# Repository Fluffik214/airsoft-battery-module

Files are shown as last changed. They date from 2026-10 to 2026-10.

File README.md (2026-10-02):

# Airsoft Battery Module

This is a USB-C PD charger and cell monitor for a **3S LiPo** that lives in an airsoft stock tube. It has one USB-C port. A PD charger charges the pack through it, and a phone plugged into the same port shows each cell's voltage and charge % in the companion Android app.

| | |
|---|---|
| Board | 135 × 21 mm, 2 layers, SMT only, no BGA |
| Pack | 3S LiPo (made for an iPower 1450 mAh stick). Deans main lead, JST-XH balance plug |
| Charging | USB-C PD at 15 V (CH224K) → BQ25798 buck-boost charger |
| Monitoring | BQ7692003 (per-cell voltage, NTC, balancing) → STM32F042 → USB CDC |
| Idle drain | about 1 µA when unplugged |

## How it works

- **One port, two jobs.** On a PD charger the module charges. On a phone it only reports (5 V never charges, so the phone isn't drained). It never does both at once.
- **Charging rules:**
  - It starts after USB has stayed between 12 and 17 V for 5 s, then charges to your preset: Full, a custom %, Storage (3.80 V/cell) or Off.
  - If USB goes above 17 V, charging is cut immediately.
- **Per-cell control, like a hobby balance charger.** When a cell is full, it is held there and bled while the current is turned down, so the other cells can catch up. No cell goes more than 10 mV over the target.
- **JP2 solder jumper (back of the board).** Open (default) = slow charge, 700 mA. Bridged = fast charge, 1.4 A. Both currents can be changed in the app.
- **Event log in flash.** Faults (over-voltage, over-temperature, bad cell…) and a report for every charge are stored on the module. The app shows them the next time a phone is connected.

## Repository layout

| Path | Contents |
|---|---|
| `usbc pd airsoft module.kicad_*` | KiCad 10 project: schematic, routed PCB, design rules |
| `schematic.pdf`, `bom.csv` | Schematic printout and bill of materials |
| `DESIGN_NOTES.md` | Hardware notes: power path, pinouts, checks before first power-up |
| `layout_work/` | Python scripts that generated the schematic and placed/routed the PCB |
| `firmware/` | STM32F042 firmware: bare-metal C plus TinyUSB. **`firmware/README.md` is the full guide**, covering protocol, settings, safety rules and how to customize |
| `android/` | Android app: Kotlin, Jetpack Compose, Material 3 |
| `release/` | Prebuilt firmware (`.bin` / `.hex`) and app (`.apk`) |
| `production/` | Gerber zip for the board house, drill files, pick-and-place, BOM, assembly drawings, and `ORDERING.md` (fab settings) |

## Quick start

1. **Flash the firmware.** A blank chip starts in the USB DFU bootloader. You can also bridge JP1 while plugging in. Then:
   ```
   dfu-util -a 0 -s 0x08000000:leave -D release/airsoft_charger.bin
   ```
   STM32CubeProgrammer works too.
2. **Install the app.** Copy `release/PDCharger-1.0.0.apk` to the phone and install it.
3. **Check the pack.** Plug the module into the phone with a USB-C cable and open the app.
4. **Charge it.** Put the module on a USB-C PD charger that offers 15 V (or 12 V).

### Building from source

- **Firmware:** needs `arm-none-eabi-gcc` (tested with xPack 15.2.1). Run:
  ```
  python firmware/build.py --gcc <path-to-toolchain-bin>
  ```
- **App:** needs JDK 17 and the Android SDK. Run:
  ```
  cd android && ./gradlew assembleRelease
  ```

## Safety

LiPo batteries can catch fire. This is a hobby project with **no warranty**. Check `DESIGN_NOTES.md` before the first power-up. In particular, confirm that the balance plug's pin 1 is the pack's negative wire.

## License

© Fluff. Licensed under **[Creative Commons Attribution-NonCommercial-ShareAlike 4.0](LICENSE)** (CC BY-NC-SA 4.0):

- You may copy, build and change this project for **non-commercial** use, if you credit the author and share your changes under the same license.
- **Commercial use, including selling boards, kits or devices built from this design, needs written permission from the author.**

Third-party code in `firmware/lib/` keeps its own license:

- **TinyUSB:** MIT, see `firmware/lib/tinyusb/LICENSE`.
- **ARM CMSIS core headers:** Apache-2.0 (SPDX header in each file).
- **ST device headers:** Apache-2.0, see `firmware/lib/cmsis/LICENSE-ST-cmsis-device-f0.md`.

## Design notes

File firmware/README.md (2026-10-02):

# Airsoft PD Charger: firmware guide

This firmware runs on the **STM32F042F6P6** of the Rev A board. It is bare-metal C: CMSIS registers plus TinyUSB for the USB serial port. There is no HAL and no RTOS.

| | |
|---|---|
| Flash used | **26.0 KB of 30 KB** (+ 1 KB event-log page + 1 KB settings page) |
| RAM used | **3.0 KB of 6 KB** (plus 1 KB reserved for the stack) |
| Clock | 48 MHz HSI48, trimmed to USB by CRS (no crystal) |
| USB | CDC-ACM virtual serial port. VID/PID `0x1209/0x0001` (pid.codes *test* ID) |
| Output | `build/airsoft_charger.bin` / `.hex` (also copied to `../release/`) |

---

## 1. What the module does

> **One USB-C port.** The module is *either* on a charger (charging, no phone) *or* on a phone (talking, 5 V, never charging). It is never both at once. The app therefore never sees a charge live. It sets the plan beforehand and reads the **charge report** from the log afterwards.

Charging is decided by **the USB voltage only**:

```
              USB-C plugged in → MCU boots (powered from VBUS via the LDO)
                                   │
          ┌────────────────────────┼─────────────────────────┐
     VBUS < minvin (12 V)     12 V ≤ VBUS ≤ 17 V        VBUS > 17 V
     phone / 5 V charger      (PD charger at 15 V)      (broken charger)
          │                        │                         │
     monitor only             stays in window for       charging cut at once
     (state HOST if the       cfg.wait_s (default 5 s)  (CHG_EN low in < 1 ms),
      app is talking,               │                   fault logged; must be back
      else MONITOR)           charge by the plan        in the window for 5 s again
                       ┌───────────┼──────────────┐
                  mode 0: to   mode 1: storage  mode 2: off
                  tgt %        (bleed if above) (monitor)
                       └── charger stops itself at the target (CV + termination)
     USB unplugged → (optional balancing for "bun" minutes) → charger SHUTDOWN
                   + monitor SHIP + PWR_HOLD low = ~1 µA total
```

- **Phone:** it gives 5 V, so the module never charges from it. It only answers the app's requests (`s?`, `c?`, `log?` …). Talking to the app does **not** affect charging any more; `host` is just information.
- **PD charger:** 15 V lands in the window, and after 5 s the module charges to the preset % and stops.
- **Over-voltage:** `app_fast()` runs on every main-loop pass, not just every 250 ms. After 3 readings in a row above 17 V it drops `CHG_EN`, which switches the charger off in hardware through Q1 and /CE. As a second layer, the BQ25798's own input over-voltage cutoff is set to 18 V (`VAC_OVP`, re-applied every 5 s).

> The limit is `VBUS_MAX_MV` = 17000 in `board.h`. PD chargers may give up to 15.75 V when asked for 15 V, which leaves about 1.2 V of margin for ADC error.

## 2. File map

| File | What it is | Edit it when… |
|---|---|---|
| `src/board.h` | Pin map, I²C addresses, VBUS divider, version strings | you change the schematic or bump the version |
| `src/main.c` | Startup order, main loop, USB send/receive, `delay_hook` | you change the loop timing or USB handling |
| `src/app.c / app.h` | **Everything that matters**: state machine, safety, balancing, LED, JSON status, commands | you change behavior |
| `src/config.c / config.h` | Settings struct, defaults, allowed ranges, flash save with CRC | you add or change a setting |
| `src/soc.c / soc.h` | LiPo voltage↔% table, IR correction while charging | your packs have a different curve |
| `src/log.c / log.h` | Event log in its own flash page (faults, charge start/end, watchdog resets) | you want to log more things |
| `src/bq25798.c / .h` | Charger IC driver (registers, ADC readout, enable/HIZ/shutdown) | you need another charger feature |
| `src/bq76920.c / .h` | Cell monitor driver (CRC I²C, gain/offset, NTC, balance, ship) | you change cell wiring or the NTC |
| `src/hw.c / hw.h` | Clock, SysTick, GPIO, ADC, I²C, LED PWM, watchdog, flash, ROM-bootloader jump | low-level hardware changes |
| `src/startup.c` | Vector table and reset handler (calls `boot_check()` for DFU) | almost never |
| `stm32f042f6.ld` | Linker script: 30 KB code + 1 KB `LOG` page + 1 KB `CFG` page + 6 KB RAM | almost never |
| `src/usb_descriptors.c` | USB VID/PID, names, serial number (from the chip UID) | **before selling anything** (VID/PID) |
| `src/tusb_config.h` | TinyUSB options and buffer sizes | rarely |
| `lib/tinyusb` | TinyUSB (trimmed to device + CDC + STM32 FSDEV) | never |
| `lib/cmsis` | ARM/ST register headers | never |
| `build.py` | Build script (no `make` needed) | adding source files |

---

## 3. Building

You need an `arm-none-eabi-gcc` toolchain. The one used here is xPack GCC 15.2.1, unpacked at `C:\Users\duzik\.xpack\arm-gcc`.

> **Windows tip:** keep the toolchain in a short path. GCC fails with "machine/_default_types.h: No such file" when its path is longer than about 260 characters.

```
cd firmware
python build.py --gcc C:/Users/duzik/.xpack/arm-gcc/bin
```

You can also put the toolchain on `PATH` or set the `ARM_GCC_BIN` environment variable. `python build.py clean` deletes `build/`.

The build prints flash and RAM usage at the end. **Keep FLASH under 30 KB.** The last two pages hold the event log and your settings, and the linker refuses to overflow into them.

To add a `.c` file, append it to `SRC` in `build.py`.

---

## 4. Flashing

The chip has a USB DFU bootloader in ROM, so no programmer is needed.

| Situation | How to get into the bootloader |
|---|---|
| Brand-new (blank) chip | Plug in USB. A blank STM32F042 boots straight into the ROM bootloader. |
| Firmware running | App → Settings → Advanced → **Bootloader (DFU)**, or send `dfu` over serial |
| Firmware broken | Bridge **JP1** (BOOT0 to 3V3) while plugging in USB |
| SWD instead | Test pads TP5 SWDIO, TP6 SWCLK, TP7 3V3, TP8 GND (back side) plus an ST-Link |

Then flash from a PC:

```
STM32CubeProgrammer:  Port = USB → Connect → Open airsoft_charger.bin at 0x08000000 → Download
dfu-util:             dfu-util -a 0 -s 0x08000000:leave -D airsoft_charger.bin
```

On Windows, dfu-util needs the WinUSB driver for "STM32 BOOTLOADER" (use Zadig). CubeProgrammer installs its own driver.

Settings live in the 1 KB page at `0x08007C00` and the event log at `0x08007800`. Flashing only the `.bin` keeps both. A full chip erase resets the settings to defaults and empties the log.

---

## 5. Settings (stored in flash)

All settings are set with `set <key> <value>`, and `save` writes them to flash. Defaults and limits are in `config.c`: change `config_defaults()` and the `fields[]` table.

| Key | Meaning | Default | Range | Unit |
|---|---|---|---|---|
| `mode` | 0 = charge to `tgt`, 1 = storage, 2 = never charge | 0 | 0–2 | |
| `tgt` | charge target in mode 0 (100 = full = `vcell`) | 100 | 50–100 | % |
| `wait` | USB must stay in the 12–17 V window this long before charging starts | 5 | 1–600 | s |
| `vcell` | full-charge voltage per cell | 4200 | 4000–4200 | mV |
| `ichs` | **slow** charge current, used while JP2 is open (default) | 700 | 100–3000 | mA |
| `ichg` | **fast** charge current, used when JP2 is bridged | 1400 | 100–3000 | mA |
| `iin` | USB input current limit (1.5 A keeps an 18 W 12 V charger and a 20 W 15 V charger within rating) | 1500 | 500–3000 | mA |
| `stor` | storage voltage per cell | 3800 | 3700–3900 | mV |
| `minvin` | lower edge of the charging window (the upper edge is `VBUS_MAX_MV` = 17 V in `board.h`) | 12000 | 9000–15000 | mV |
| `bal` | balancing on/off | 1 | 0–1 | |
| `balth` | balance when the cell spread is above this | 15 | 5–60 | mV |
| `balmin` | never bleed a cell below this voltage | 3900 | 3500–4150 | mV |
| `bun` | keep balancing on pack power after unplug | 0 | 0–60 | min |
| `imb` | refuse to charge above this cell spread | 300 | 50–500 | mV |
| `tmax` | max pack temperature while charging | 45 | 35–60 | °C |
| `cap` | pack capacity (used for the ETA) | 1450 | 200–10000 | mAh |
| `led` | LED brightness | 40 | 0–100 | % |
| `rate` | status report interval | 500 | 200–5000 | ms |

**How `tgt` becomes a voltage:** `target_mv()` in `app.c` runs `soc_to_mv(tgt)` (the inverse of the OCV table) and caps the result at `vcell`. The charger's VREG is set to 3 × that value. The BQ25798 then does a normal CC/CV charge to that voltage and terminates by itself.

| Target | Per cell | Pack |
|---|---|---|
| 80 % | ≈ 4.04 V | ≈ 12.1 V |
| 100 % | 4.20 V | 12.6 V |

**Adding a new setting:**

1. Add a field to `config_t` before `crc`.
2. Set its default in `config_defaults()`.
3. Add a line to `fields[]`.
4. Add it to `send_cfg()` in `app.c`.
5. If the layout changed, bump `CFG_MAGIC` so old flash contents are ignored instead of misread.
6. In the app, add it to `ConfigKey` in `Models.kt`.

---

## 6. Serial protocol (what the app speaks)

The protocol is plain text lines ending in `\n`. Any terminal works at any baud rate, but **DTR must be on**, because the firmware only sends while a terminal is open. Every reply is a single JSON line.

### Commands

| Command | Reply / effect |
|---|---|
| `s?` | status line now (status also streams every `rate` ms) |
| `c?` | `{"t":"cfg", …all keys…}` |
| `i?` | `{"t":"i","fw":"1.0.0","hw":"RevA","uid":"…","chg":1,"bms":1}` (chg/bms = chips found) |
| `set <key> <int>` | `{"t":"ok","m":"<key>"}` then the cfg line, or `{"t":"err","m":"bad key/value"}` |
| `save` | writes the settings to flash |
| `defaults` | resets the settings in RAM (send `save` afterwards to keep them) |
| `mode charge\|storage\|monitor` | same as `set mode 0/1/2` |
| `reboot` | soft reset |
| `dfu` | jump to the ROM USB bootloader |
| `ship` | refused while USB is present (shipping happens automatically on unplug) |
| `log?` | the whole event log: one `{"t":"log","b":boot,"s":sec,"c":code,"v":value}` per entry (oldest first), then `{"t":"logend","n":count,"boot":current}` |
| `logclr` | erase the event log |

### Status line

```json
{"t":"s","st":"HOST","md":"charge","src":"LOW","vbus":5040,"ibus":0,"pack":11520,"ibat":0,
 "c":[3841,3838,3840],"p":[48,47,48],"soc":48,"tp":243,"tc":312,"bal":0,"flt":256,"chg":0,
 "eta":-1,"up":12,"host":1,"arm":-1,"tgt":4200}
```

| Field | Meaning |
|---|---|
| `st` | state (see the next table) |
| `md` | `charge` / `storage` / `monitor` |
| `src` | `NONE` (< 4 V), `LOW` (below `minvin`), `PD` (in the window), `HIGH` (> 17 V) |
| `vbus` / `ibus` | USB voltage (mV) and current (mA) |
| `pack` / `ibat` | pack voltage (mV) and battery current (mA, + = charging) |
| `c[]` | cell 1–3 voltages (mV) |
| `p[]` | per-cell % |
| `soc` | pack % (average of the cells, IR-corrected while charging) |
| `tp` / `tc` | pack NTC / charger die temperature, 0.1 °C |
| `bal` | balance bitmask (bit0 = cell 1) |
| `flt` | fault bits (see section 8) |
| `chg` | charging enabled |
| `eta` | minutes to full, -1 = n/a |
| `up` | uptime (s) |
| `host` | 1 = the app has sent a command (information only) |
| `arm` | seconds until charging starts (VBUS in window, counting down), -1 = not counting |
| `tgt` | per-cell target voltage of the current plan (mV) |
| `logn` | number of entries in the event log. The app re-reads the log when this changes. |
| `ich` / `full` / `fast` | current charge-current limit (mA), all cells full (0/1), JP2 bridged = fast (0/1) |

### States (`st`)

| State | Meaning | LED |
|---|---|---|
| `ARMING` | 12–17 V seen, counting down `wait` | slow dim blink |
| `HOST` | on 5 V with the app talking (phone) | short flash every 2 s |
| `PRECHARGE`, `CC`, `CV`, `TOPOFF` | charging phases reported by the BQ25798 | breathing |
| `STORAGE` | charging toward the storage voltage | breathing |
| `DONE` | target reached | solid |
| `BALANCE` / `BLEED` | bleeding high cells / storage discharge | double blink |
| `MONITOR` | mode 2 or 5 V source, nothing charging | short flash |
| `FAULT` | a blocking fault (see `flt`) | fast blink |
| `UNPLUGGED` | no USB power, shutting down | off |

---

## 7. Main loop and timing (`main.c`)

```
hw_init → config_load → app_init (PWR_HOLD high, log_init + reset cause, init chips) → tusb_init → wdg_init (~2 s)
loop:  wdg_feed · app_fast (17 V cut) · tud_task · read USB lines
       every 250 ms: app_tick()       every loop: app_led()
       every cfg.rate ms (or on "s?"): send the status JSON
```

- **`app_tick()`**: reads both chips, evaluates faults, decides charging, picks the balance cells (every 2 s), sets the state, and handles unplug.
- **Charger watchdog**: kicked every 1 s. Its settings are rewritten every 5 s, so if the BQ25798 ever resets to its defaults, the firmware puts your values back.
- **`delay_ms()`**: calls `delay_hook()`, which keeps USB and the watchdog serviced during the 300–400 ms cell-monitor boot wait.

---

## 8. Safety rules (`app_tick()` in `app.c`)

| Bit | Name | Trigger | Blocks charging |
|---|---|---|---|
| 0 | `F_NOBATT` | pack < 6.0 V | yes |
| 1 | `F_CELL_OV` | any cell > 4250 mV **or** > `vcell` + 50 | yes |
| 2 | `F_CELL_UV` | any cell < 2500 mV (only with a battery present) | yes |
| 3 | `F_IMBAL` | spread > `imb` | yes |
| 4 | `F_HOT` | pack > `tmax`, or charger die > 110 °C | yes |
| 5 | `F_COLD` | pack < 0 °C (readings below −40 °C are treated as "no NTC") | yes |
| 6 | `F_CHG` | BQ25798 FAULT0 ≠ 0 or FAULT1 & 0xC4 | yes |
| 7 | `F_BMS` | cell monitor not answering | yes |
| 8 | `F_LOWSRC` | VBUS < `minvin` (info only: phone or 5 V charger; not logged) | no (but no charge) |
| 9 | `F_CHGCOMM` | charger not answering while USB is present | yes |
| 10 | `F_OVERVOLT` | VBUS > 17 V (`VBUS_MAX_MV`). Cut instantly by `app_fast()`. | yes |

**Extra rules:**

- **Per-cell charge control (like a hobby balance charger):** the BQ25798 only sees the whole pack, so the firmware handles single cells:
  - **Hold:** if any cell reaches target + 10 mV (`CELL_MAX_OVER`), charging pauses at once. It resumes in short bursts when that cell is ≤ target + 2 mV.
  - **Taper:** when the highest cell is within 20 mV of the target (`CELL_TAPER_AT`) and the spread is > `balth`, the charge current drops by 25 % every 2 s, down to 50 mA (`ICHG_MIN_MA`). The full cell's bleed then keeps it level while the lower cells fill. The current steps back up by 100 mA every 2 s once the highest cell is 60 mV below the target.
  - **Full:** every cell is within 25 mV of the target (`CELL_FULL_AT`), measured at < 150 mA so internal resistance can't fake it. Charging then stops and stays stopped until unplugged.
  - Shown as state `CELLCV`. The status adds `ich` (current limit in mA) and `full` (0/1).
  - **Speed limit:** the cells even out at the bleed rate (~37 mA per cell, 70 % duty). A normal pack (~25 mV apart) adds roughly 45 min; a badly neglected one (>100 mV) can take hours.
- **Balancing:** the highest cell bleeds when it is > `balmin` and the spread > `balth`. Cells 1 and 3 may bleed together, but adjacent cells never do (BQ76920 rule).
- **Storage mode:** if the lowest cell is already above `stor` + 20 mV, the firmware alternates bleeding cells 1+3 and cell 2. This only happens while armed, never on a phone.

To make the module stricter or looser, edit these numbers in `app_tick()`.

---

## 8b. Event log (`log.c`)

The log is a 1 KB flash page with 128 entries of 8 bytes each: `{boot, seconds since that power-up, code, value}`. When the page is full, the newest 64 entries are kept and the page is rewritten.

| Code | Event | Value |
|---|---|---|
| 0–10 | fault bit *n* started (see the table above) | the measurement that caused it (mV, mV spread, 0.1 °C, charger fault registers, USB mV) |
| 32 | charging started | pack mV |
| 33 | charge complete (target reached) | pack mV |
| 34 | firmware was reset by the watchdog (hang) | – |
| 35 | cell monitor failed to boot | – |
| 36 | charging stopped by a fault | fault bits |
| 37 | log cleared | – |
| 38 | unplugged before the target was reached | pack mV |
| 39 | charge report: mAh put into the pack | mAh |
| 40 | charge report: minutes from charge start to unplug | min |
| 41 | charge report: peak pack temperature | 0.1 °C |
| 42 | charge report: pack voltage when charging started | mV |

- **Faults** are logged **once per power-up** each (`log_once`). This keeps a flapping fault from wearing out the flash, which is rated for about 10 000 erase cycles.
- **Charge report:** `32` is written once when charging starts. When the charger is unplugged, the firmware still runs on the pack for about 1.5 s and writes the result: `33` (target reached) or `38` (unplugged early), followed by `42`, `39`, `40` and `41`. The app combines these into **Last charge** and **Charge history**.
- **Power-up number:** each power-up gets the next number, so the app can group events by power-up.

To log something new, call `log_event(code, value)` or `log_once(code, value)` with a code from 38 to 63, then add it to `EventKind` in the app's `EventLog.kt`.

## 9. Common customizations

| I want to… | Change |
|---|---|
| Change the charging window | `minvin` setting (lower edge) and `VBUS_MAX_MV` in `board.h` (upper edge) |
| Start charging faster or slower | `set wait <seconds>` (1–600) |
| Different default plan (e.g. 80 %) | `config_defaults()`: `cfg.tgt_pct = 80;` and bump `CFG_MAGIC` |
| A 2S or 4S pack | `target_mv()` multiplier (`* 3` in `charger_apply`), the `bq76920.c` cell mapping, `bq25798_configure` VREG clamps, the `F_NOBATT` threshold. The hardware (PROG resistor, cell wiring) must also change. |
| Faster charging | bridge **JP2** (back of the board, under the MCU) with solder → uses `ichg` (1.4 A) instead of `ichs` (0.7 A). Both are settable in the app. |
| Tighter "full" (closer to 4.20 V on every cell) | `CELL_FULL_AT` in `app.c` (default 25 mV; smaller = longer final balance) |
| Different LED patterns | `app_led()` in `app.c` (`b` = brightness 0–100, `t` = ms) |
| A different SOC curve | `ocv_mv[]` / `ocv_pc[]` in `soc.c` (keep the app's `Ocv` table in `Models.kt` the same) |
| Your own USB name | `strings[]` in `usb_descriptors.c` |
| Your own VID/PID | `USB_VID/USB_PID` in `usb_descriptors.c` **and** `res/xml/device_filter.xml` + `CdcConnection.VID/PID` in the app |
| New command | add a branch in `app_command()` (`app.c`) |
| New status field | add `kv(&w, "name", value);` in `app_status_json()`. Keep the line under 360 chars (the buffer size in `main.c`). |

---

## 10. Hardware notes the firmware relies on

| Item | Detail |
|---|---|
| USB pins | USB D−/D+ are on PA11/PA12 via the SYSCFG remap (`PA11_PA12_RMP`), which `hw.c` enables |
| BQ25798 | I²C 0x6B. PROG = 10.5 k → 3S, 1.5 MHz. /CE is driven by Q1 from `PIN_CHG_EN`, so charging needs **both** the pin high and the EN_CHG bit set. D+/D− are not connected, so BC1.2/HVDCP detection is disabled in `bq25798_init()`. |
| BQ7692003 | I²C 0x08 with CRC-8. Booted by a pulse on TS1 (`PIN_BMS_BOOT`). 3S wiring: cells are VC1−VC0, VC2−VC1, VC5−VC4. Cell input resistors R13–R16 = 56 Ω → ~37 mA balance current (datasheet min 40 Ω / max 50 mA). |
| CH224K | Hard-wired for 15 V (CFG1 = 56 k). The firmware only *measures* VBUS (÷ 11 on PA5). |
| JP2 | Solder jumper PB1 → GND (internal pull-up), on the back under U6. Open = slow (`ichs`), bridged = fast (`ichg`). Read every tick (`fast_jumper()` in `hw.c`). |
| Power | MCU 3.3 V from the AP7381 LDO. `PIN_PWR_HOLD` keeps it on from the pack after unplug, and it is dropped in `shutdown_now()`. |
| Watchdog | IWDG ≈ 2 s. A hang resets the MCU, and the charger is disabled again until the firmware re-decides. |

---

## 11. First power-up checklist

1. Flash it, then plug it into a **PC** (it enumerates as *PD 3S Charger*). Open any serial terminal and send `i?`. Both `chg` and `bms` should be `1` with a pack connected.
2. Send `s?` and check the cells against a multimeter. They should be within ~10 mV.
3. `set led 100` → the LED gets brighter (no save needed).
4. Unplug the PC and plug into a PD charger. The LED dims and slow-blinks for 5 s, then starts breathing (charging). Afterwards, connect the phone and check the **Event log**: you should see "Charging started".
5. Unplug: everything should be off within ~2 s (total pack drain about 1 µA).

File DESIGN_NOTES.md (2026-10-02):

# USB-C PD 3S LiPo charger module: design notes (Rev A)

Target pack: iPower 1450 mAh 3S 20C stick (110 × 20 × 15 mm). It has a Deans T-plug main lead and a white JST-XH 4-pin balance plug.
Board outline: **135 × 20–21 mm**. The single USB-C port goes on one short edge.

## Power path
USB-C (J1, the only USB port) → CH224K asks for 15 V (R2 = 56k) → BQ25798 buck-boost charger → F1 (3 A) → **Deans main lead**.
- **Battery and gun are wired pass-through**:
  - Battery Deans pigtail → BATT IN +/− pads (TP1/TP3).
  - Gun Deans pigtail → GUN OUT +/− pads (TP2/TP4).
  - Put each IN/OUT pair side by side and join it with a short solid pour on both layers plus vias (or solder both wires to one pad). That way gun current never runs along the board.
  - Use 16 AWG silicone wire.
- The balance plug (J2, JST-XH) is **sense and balance only**. It carries no charge current, so the cell readings stay accurate.
- **JP2 (FAST CHARGE solder jumper, back side under the MCU):** MCU PB1 to GND with the internal pull-up. Open (default) = slow charge, 700 mA. Bridged = fast charge, 1.4 A. Both currents can be changed in the app. Added 2026-10-02.
- The BQ7692003 measures each cell and balances them (~37 mA bleed: Rc = R13–R16 = 56 Ω, changed from 100 Ω on 2026-10-02 to roughly double the balance speed).
- The STM32F042F6P6 runs from 3V3 (AP7381). 3V3 comes from VBUS (a charger or a phone), or from the pack through Q2 while the MCU asserts PWR_HOLD.

## Field check (no extra pins)
1. Plug a phone into the module's USB-C port (C-to-C cable) and open the app.
2. The phone's 5 V powers the MCU. It reports volts and % per cell, settings and the event log over USB CDC.
3. Charging only happens at 12–17 V, so the phone is never drained. One USB-C port: the module is either on a charger or on a phone, never both.

## Idle battery drain (target ~1–2 µA)
BQ25798 in shutdown mode (0.5 µA) + BQ76920 in SHIP mode (~0.6 µA) + leakage. **After you first connect a pack, plug USB in once.** Until then the BQ25798 stays in battery-only mode and draws ~17 µA.

## Firmware bring-up (STM32F042, I2C1 on PF0/PF1)
1. On boot, set SYSCFG PA11_PA12_RMP so USB uses pins 17/18, and start USB CDC.
2. **BQ76920 (0x08, CRC on)**: drive PA4 high for 5 ms then set it to analog (this boots it from SHIP). Wait 250 ms, then set ADC_EN and read the gain/offset. Cells are VC1-VC0, VC2-VC1 and VC5-VC4 (3S wiring: VC2=VC3=VC4).
3. **BQ25798 (0x6B)**: clear AUTO_INDET_EN and HVDCP_EN, set IINDPM to suit the source, set **ICHG = 1.4 A** (1C for 1450 mAh), check VREG = 12.6 V, kick the watchdog (or disable it).
4. Only drive **CHG_EN (PA2) high** when all of these are true (as implemented in firmware/src/app.c):
   - VBUS_SENSE has been inside 12–17 V for `wait` seconds (default 5 s). Above 17 V, charging is cut instantly.
   - Every cell is between 2.5 V and the target, and the pack is present.
   - The cells are within `imb` (300 mV) of each other.
   - The temperature is within limits.
   - Note: the charger must offer 15 V (or 12 V) PD. The CH224K datasheet doesn't say what happens when 15 V isn't offered (it may stay at 5 V or take a lower level). If you see a 9 V brick charging-blocked at 9 V, lower `minvin` to 9000 in the app; the buck-boost charger handles 9 V fine.
5. While charging: per-cell control like a hobby balance charger. A full cell is held (charging pauses above target + 10 mV, current tapers to 50 mA) and bled while the others catch up. "Full" = every cell within 25 mV of the target. Never balance two adjacent cells at once. See firmware/README.md section 8.
6. On unplug (VBUS_SENSE falls or the BQ25798 INT fires):
   1. Assert **PWR_HOLD (PA7)**.
   2. Finish balancing if wanted.
   3. Write BQ25798 SDRV_CTRL = 01 (shutdown).
   4. Put the BQ76920 into SHIP.
   5. Release PWR_HOLD.
7. If it was powered by a phone (VBUS ≈ 5 V): report the cells over CDC and never enable charging.
8. Faults and a per-charge report are written to the event-log flash page; the app reads them later.

## Flashing
There's no SWD header. Bridge JP1 (BOOT0) and plug in USB-C to enter the ST ROM DFU bootloader, then use STM32CubeProgrammer or dfu-util. A blank STM32F042 also starts in the bootloader on its own.

## Before you order PCBs (check these)
- **Balance plug pinout**: J2 pin 1 = pack negative. Check it against the pack.
- **Deans gender**: the battery-side pigtail must mate with the pack, and the gun-side one with the gun.
- **CH224K VDD resistor (R1 = 1k, 1206)**: I couldn't read the value off WCH's reference schematic image. 1k is the common community value.
- **Layout**:
  - BQ25798 power loop as tight as possible (VBUS/PMID caps, L1, SYS caps).
  - Thermal-pad vias under U3.
  - TH1 at the board edge facing the pack.
  - Cell sense traces (R12–R16) kept away from SW1/SW2.

## PCB layout (Rev A, routed 2026-10-02)
- **Board:** 135 x 21 mm, 2 layers. 349 tracks, 154 vias (61 of them GND stitching). Ground pours on both layers, solid connection.
- **Final check:** DRC shows 0 errors, 0 unconnected and 0 schematic-parity issues. The only warnings are silkscreen (the USB-C outline at the edge, and the charger's pin-1 marker touching a cap pad).
- **Corners:** no 90-degree corners anywhere. Every trace bend is a 45-degree chamfer, every branch joins at 45 degrees (checked by `layout_work/audit.py`), and all copper zones have chamfered outlines (0.4 mm on power, 1 mm on GND).
- **Rules (in the .kicad_pro):** 0.15 mm clearance (0.2 mm on power nets), 0.2 mm signals, 0.8–1.0 mm power, vias 0.6/0.3 and 0.5/0.25.
- **Parts on the BACK side (8):**
  - C5, C6 (charger bootstrap caps, the TI-recommended placement)
  - C19 (REGN cap)
  - R5 (BATP sense resistor)
  - TP1–TP4 (Deans wire pads)

  Reflow the top first, then the back (or hand-solder the four 0402/0603 parts).
- **Deans pads (back, right end):**
  - TP1 BATT IN + and TP2 GUN OUT + share one MAIN_P copper area.
  - TP3 BATT IN − and TP4 GUN OUT − sit on the GND plane.
  - Gun current only flows pad to pad across about 1 mm of solid copper.
- **Back-side bus:** the 7 control/I²C lines run as parallel traces along the bottom edge of the back.
- **Custom text area (back):** x 198–209.8, y 101.5–116.2, about 12 × 15 mm (marked on B.Fab). It has no vias or traces, only the GND plane.
- **Reference designators:** hidden on silkscreen, kept on the Fab layers. Use KiCad's assembly view or the Fab PDF while placing parts.
- **Rebuilding the layout:** the scripts are in `layout_work/` and regenerate it deterministically (`route.py` + `regionB..E.py`).

## Rev A update (2026-10-02): J2 rotated + test pads
- **J2 (balance plug):**
  - Rotated 180°, so its opening faces the board end.
  - Moved 6 mm inward (x 218.4), so the plug body clears the two M2 screw heads at that end. Only the thin wires pass between them.
  - Its pin order is now reversed relative to the cell monitor. CELL1 and PACK_P each hop under the pads through the gaps between J2's pads. CELL2 stays on top. J2's GND pin has its own via.
- **Programming / rescue pads (back, under the MCU's top edge), 2 mm pitch:**
  - TP6 SWCLK, TP5 SWDIO, TP7 3V3, TP8 GND
  - Use them with an ST-Link if USB DFU ever fails.
  - NRST isn't brought out. If the firmware disables SWD, bridge JP1 (BOOT0) and the ROM bootloader starts instead.
- **Probe pads:**
  - TP9 VBUS (top, on the VBUS trace)
  - TP10 BAT (top, on the BAT_P trace)
  - TP11 I2C SDA and TP12 I2C SCL (top, next to the cell monitor; use them for a logic analyzer)
- **Final verification:**
  - ERC 0 errors.
  - Pin-by-pin netlist check: 204/204 pass.
  - DRC 0 errors, 0 unconnected, 0 schematic-parity issues.
  - No 90-degree corners (traces, junctions or zones).
  - No unintended vias in pads (only the CH224K thermal vias).

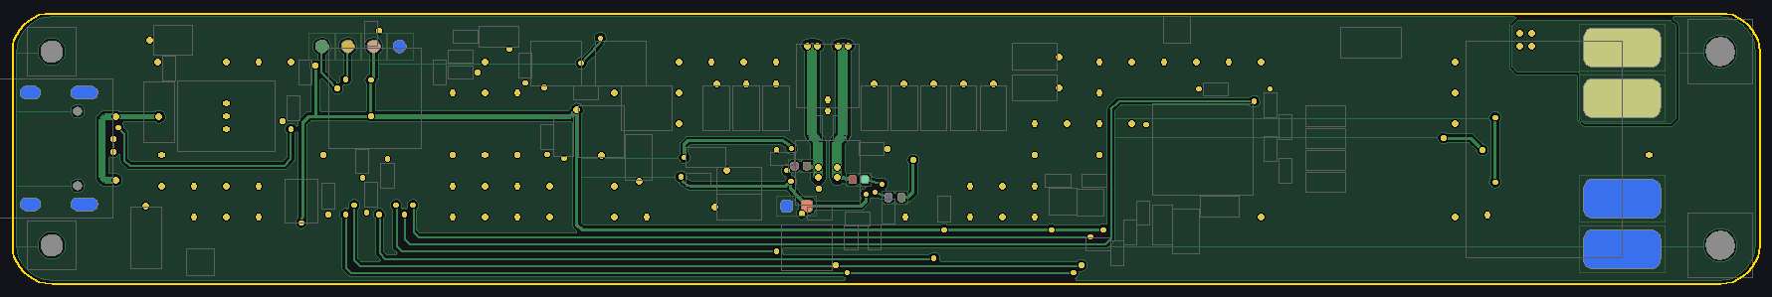
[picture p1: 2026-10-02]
layout_work/preview_bottom.png

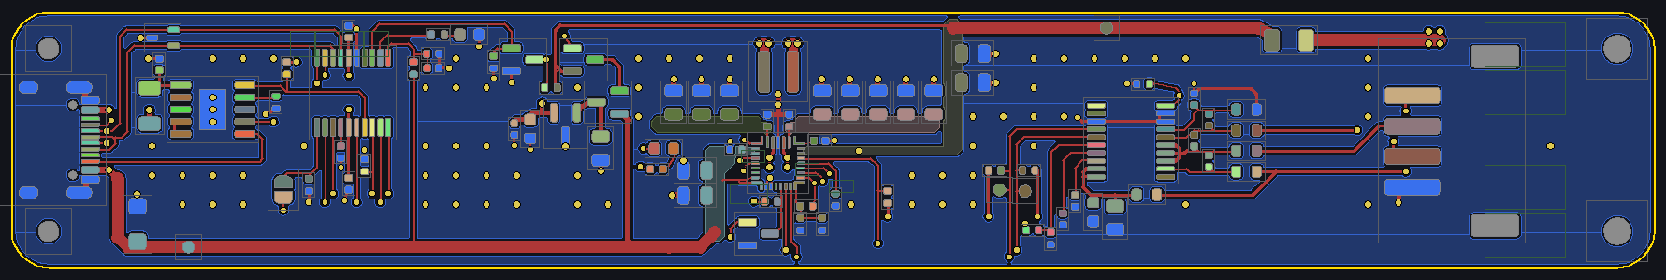
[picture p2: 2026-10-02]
layout_work/preview_top.png

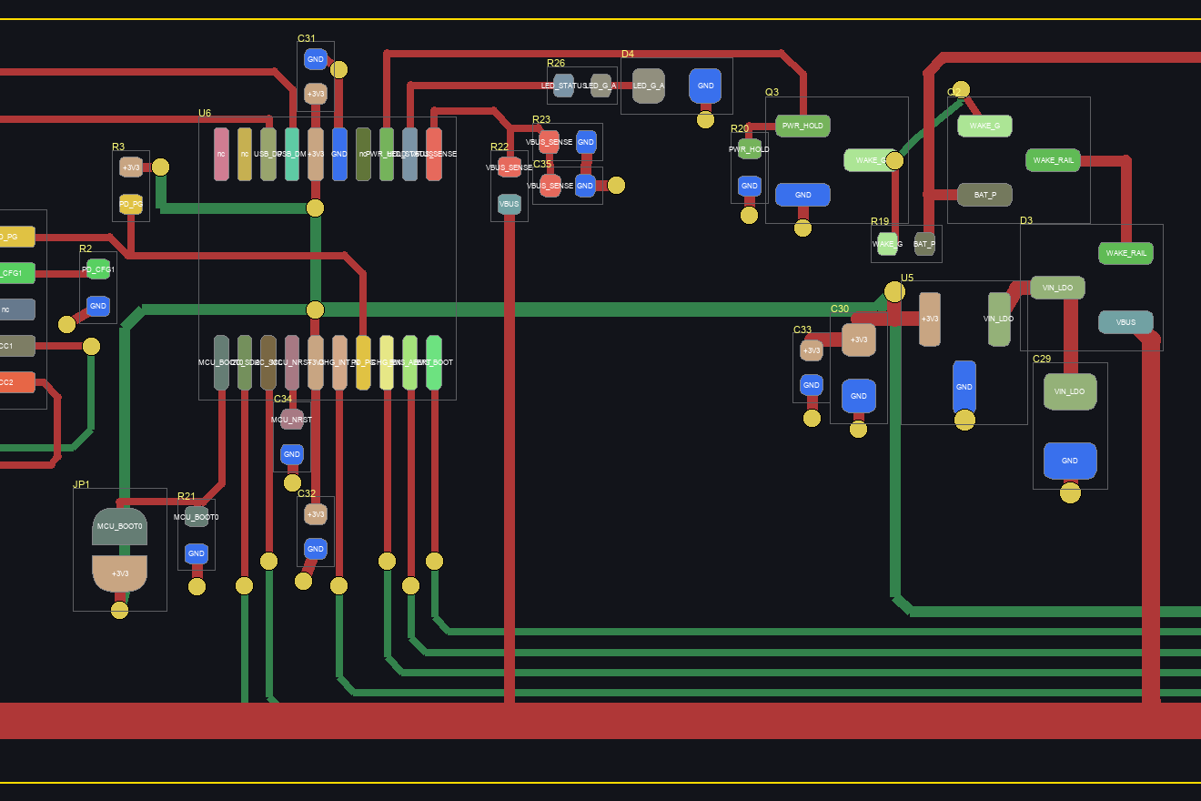
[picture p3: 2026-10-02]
layout_work/rB.png

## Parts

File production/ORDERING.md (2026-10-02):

# Ordering the Rev A board

## Upload

Upload `airsoft-module-rev-a-gerbers.zip`. It contains the Gerbers, the Excellon drill files (plated and unplated in separate files) and the drill maps.

## Board settings

| Setting | Value |
|---|---|
| Layers | 2 |
| Size | 135.1 × 21.1 mm |
| Thickness | 1.6 mm |
| Copper | 1 oz (35 µm) outer |
| Min track / space | 0.2 mm / 0.15 mm (standard capability) |
| Smallest drill | **0.25 mm vias** (62 of them). Standard at PCBWay. Some fabs add a small surcharge below 0.3 mm; accept it if asked. |
| Surface finish | **ENIG recommended.** Flat pads make the 0.4 mm-pitch BQ25798 QFN (U3) much easier to solder. HASL works but is bumpier. |
| Solder mask / silk | any colour |
| Castellations / edge plating | none |
| Remove order number | yes (if offered), or "specify a location" in the back-side text area |

## Stencil (recommended for hand assembly)

Order a **frameless stencil, top side**. The paste layer is `F_Paste.gtp` in the zip.

The bottom side has only 13 easy parts: 0402/0603 passives, JP2 and the test pads. Hand-solder those; no bottom stencil is needed.

## Assembly files (`assembly/`)

| File | Contents |
|---|---|
| `bom_lcsc.csv` | **Upload this to the LCSC BOM tool (lcsc.com/bom).** Every line has a verified LCSC part number (C-number) and the quantity for one board; multiply in the web tool. |
| `parts_not_at_lcsc.csv` | **Buy these somewhere else** (Mouser, DigiKey, TME, Farnell). Right now that's only **U5 = Diodes AP7381-33SA-7**: the LCSC listing was discontinued. Don't swap in another 3.3 V SOT-23 regulator. The common ones (TLV760, LM3480, HT7533, ME6203) have a different pin order and would put USB voltage on the 3.3 V rail. |
| `bom_jlcpcb.csv` | The same parts in JLCPCB assembly format (Comment / Designator / Footprint / LCSC Part #), in case JLC assembles the boards later. |
| `bom.csv` | Design BOM from the schematic, with values and notes. |
| `pick-and-place.csv` | Part positions and rotations for both sides (for PCBA or reference) |
| `assembly-top.pdf` / `assembly-bottom.pdf` | Placement drawings with pad outlines and reference designators. The bottom one is mirrored, as seen from the back. |

## Parts notes (checked 2026-10-02)

- **U5 AP7381-33SA-7:** not available at LCSC; see `parts_not_at_lcsc.csv`.
- **U1 CH224K (C970725):** only 3 in stock at LCSC. Fine for up to 3 boards; for more, buy extra CH224K elsewhere.
- **C31/C32/C34/C35:** C6119778 (100 nF 25 V), the part LCSC's BOM tool proposes for this line. The design needs ≥ 16 V.
- **Minimum order:** LCSC sells most 0402/0603 passives in lots of 100, so expect spare parts.
- **Stock changes daily:** re-check the BOM tool result right before you pay.

## Before you place the order

1. Add your custom text on the back silkscreen in the reserved area (x 198–210 mm, y 101–116 mm), then re-export the Gerbers.
2. Check the J2 balance-plug orientation against your pack: pin 1 = black (negative).
3. Solder order: U3 (QFN) and U1 first with paste and hot air or a hot plate, then the other ICs, then passives, then connectors last. Leave JP2 open for slow charging.

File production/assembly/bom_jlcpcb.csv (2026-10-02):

Comment | Designator | Footprint | LCSC Part #
1uF 10V | C1,C23,C24,C25,C26,C27,C28,C33 | C_0402_1005Metric | C14445
10uF 35V | C2,C3,C7,C8,C9 | C_0805_2012Metric | C440198
100nF 50V | C4,C10,C16 | C_0402_1005Metric | C2888326
47nF 25V | C5,C6 | C_0402_1005Metric | C285062
10uF 25V | C11,C12,C13,C14,C15,C17,C18,C21 | C_0805_2012Metric | C15850
4.7uF 16V | C19,C30 | C_0603_1608Metric | C19666
1nF 50V | C20 | C_0402_1005Metric | C1523
1uF 25V | C22 | C_0603_1608Metric | C29936
1uF 50V | C29 | C_0805_2012Metric | C215803
100nF 25V | C31,C32,C34,C35 | C_0402_1005Metric | C6119778
SMF20A | D1 | D_SMF | C353298
RED (charging) | D2 | LED_0603_1608Metric | C84263
BAT54C | D3 | SOT-23 | C37704
GREEN (status) | D4 | LED_0603_1608Metric | C22371299
3A 32V fast | F1 | Fuse_1206_3216Metric | C182445
USB_C_Receptacle_USB2.0_16P | J1 | USB_C_Receptacle_HRO_TYPE-C-31-M-12 | C165948
BALANCE 3S (JST-XH 4P) | J2 | JST_XH_S4B-XH-SM4-TB_1x04-1MP_P2.50mm_Horizontal | C161861
1uH | L1 | L_Coilcraft_XAL4020-XXX | C4555951
2N7002 | Q1,Q3 | SOT-23 | C8545
DMP3099L | Q2 | SOT-23 | C155244
1k | R1 | R_1206_3216Metric | C4410
56k 1% | R2 | R_0402_1005Metric | C25796
10k | R3,R9,R21,R23 | R_0402_1005Metric | C25744
10.5k 1% | R4 | R_0402_1005Metric | C226747
100R | R5 | R_0402_1005Metric | C25076
5.23k 1% | R6 | R_0402_1005Metric | C2933105
30.1k 1% | R7 | R_0402_1005Metric | C29402
2.2k | R8 | R_0402_1005Metric | C25879
100k | R10,R11,R20,R22 | R_0402_1005Metric | C25741
100R | R12 | R_0603_1608Metric | C22775
56R | R13,R14,R15,R16 | R_0603_1608Metric | C25196
1k | R17,R26 | R_0402_1005Metric | C2906864
1M | R18,R19 | R_0402_1005Metric | C26083
4.7k | R24,R25 | R_0402_1005Metric | C25900
10k B3435 (103AT) | TH1,TH2 | R_0402_1005Metric | C77131
CH224K | U1 | SSOP-10-1EP_3.9x4.9mm_P1mm_EP2.1x3.3mm | C970725
TPD2E2U06DCK | U2 | SOT-323_SC-70 | C5350871
BQ25798RQMR | U3 | Texas_RQM0029A_VQFN-29_4x4mm_P0.4mm | C2876593
BQ7692003PWR | U4 | TSSOP-20_4.4x6.5mm_P0.65mm | C601650
STM32F042F6P6 | U6 | TSSOP-20_4.4x6.5mm_P0.65mm | C2969989

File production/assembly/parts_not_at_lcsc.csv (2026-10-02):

Quantity | Manufacturer | Manufacturer Part Number | Package | Designator | Where | Why
1 | Diodes Incorporated | AP7381-33SA-7 | SOT-23 | U5 | Mouser / DigiKey / TME / Farnell | LCSC listing C3752764 discontinued. Do NOT substitute: common 3.3 V SOT-23 LDOs (TLV760, LM3480, HT7533, ME6203) have a different pin order

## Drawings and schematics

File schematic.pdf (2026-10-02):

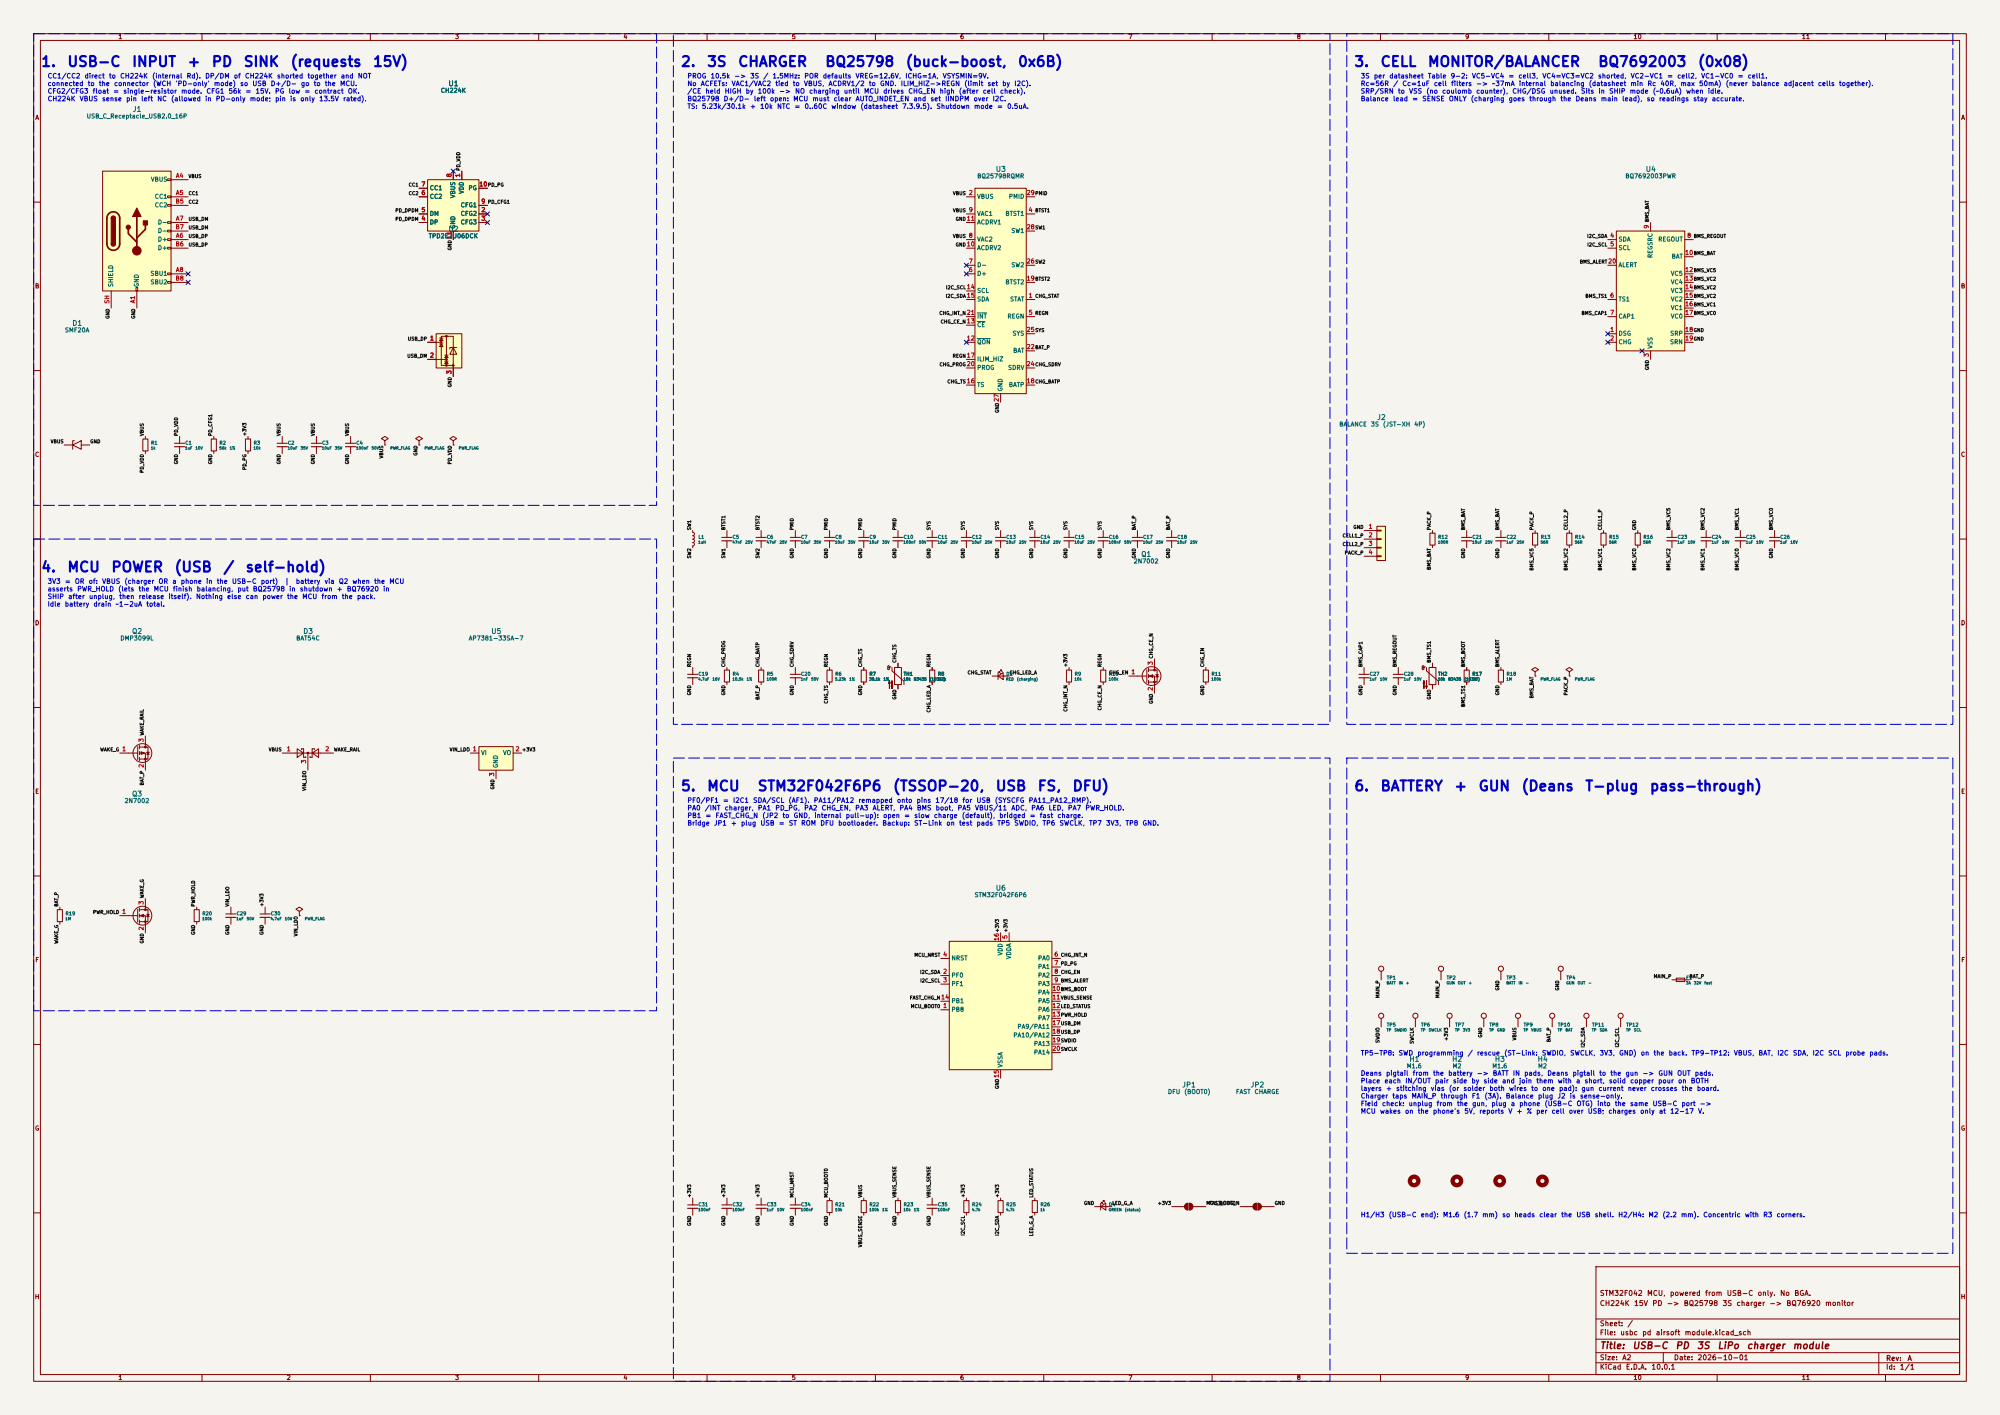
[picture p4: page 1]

BQ25798 D+/D- left open: MCU must clear AUTO_INDET_EN and set IINDPM over I2C. TS: 5.23k/30.1k + 10k NTC = 0..60C window (datasheet 7.3.9.5). Shutdown mode = 0.5uA. CC1/CC2 direct to CH224K (internal Rd). DP/DM of CH224K shorted together and NOT connected to the connector (WCH 'PD-only' mode) so USB D+/D- go to the MCU. CFG2/CFG3 float = single-resistor mode. CFG1 56k = 15V. PG low = contract OK. CH224K VBUS sense pin left NC (allowed in PD-only mode; pin is only 13.5V rated).

PROG 10.5k -> 3S / 1.5MHz: POR defaults VREG=12.6V, ICHG=1A, VSYSMIN=9V. No ACFETs: VAC1/VAC2 tied to VBUS, ACDRV1/2 to GND. ILIM_HIZ->REGN (limit set by I2C).

3S per datasheet Table 9-2: VC5-VC4 = cell3, VC4=VC3=VC2 shorted, VC2-VC1 = cell2, VC1-VC0 = cell1. Rc=56R / Cc=1uF cell filters -> ~37mA internal balancing (datasheet min Rc 40R, max 50mA) (never balance adjacent cells together).

SRP/SRN to VSS (no coulomb counter), CHG/DSG unused. Sits in SHIP mode (~0.6uA) when idle. Balance lead = SENSE ONLY (charging goes through the Deans main lead), so readings stay accurate. 5. MCU STM32F042F6P6 (TSSOP-20, USB FS, DFU)

/CE held HIGH by 100k -> NO charging until MCU drives CHG_EN high (after cell check).

4. MCU POWER (USB / self-hold)

3V3 = OR of: VBUS (charger OR a phone in the USB-C port) | battery via Q2 when the MCU
asserts PWR_HOLD (lets the MCU finish balancing, put BQ25798 in shutdown + BQ76920 in SHIP after unplug, then release itself). Nothing else can power the MCU from the pack.

TP5-TP8: SWD programming / rescue (ST-Link: SWDIO, SWCLK, 3V3, GND) on the back. TP9-TP12: VBUS, BAT, I2C SDA, I2C SCL probe pads.

H1/H3 (USB-C end): M1.6 (1.7 mm) so heads clear the USB shell. H2/H4: M2 (2.2 mm). Concentric with R3 corners. Deans pigtail from the battery -> BATT IN pads, Deans pigtail to the gun -> GUN OUT pads. Place each IN/OUT pair side by side and join them with a short, solid copper pour on BOTH

layers + stitching vias (or solder both wires to one pad): gun current never crosses the board. Charger taps MAIN_P through F1 (3A). Balance plug J2 is sense-only. Field check: unplug from the gun, plug a phone (USB-C OTG) into the same USB-C port ->

MCU wakes on the phone's 5V, reports V + % per cell over USB; charges only at 12-17 V.

STM32F042 MCU, powered from USB-C only. No BGA.
CH224K 15V PD -> BQ25798 3S charger -> BQ76920 monitor

Sheet: /
File: usbc pd airsoft module.kicad_sch
Title: USB-C PD 3S LiPo charger module

Size: A2 | Rev: A
KiCad E.D.A. 10.0.1 | Id: 1/1

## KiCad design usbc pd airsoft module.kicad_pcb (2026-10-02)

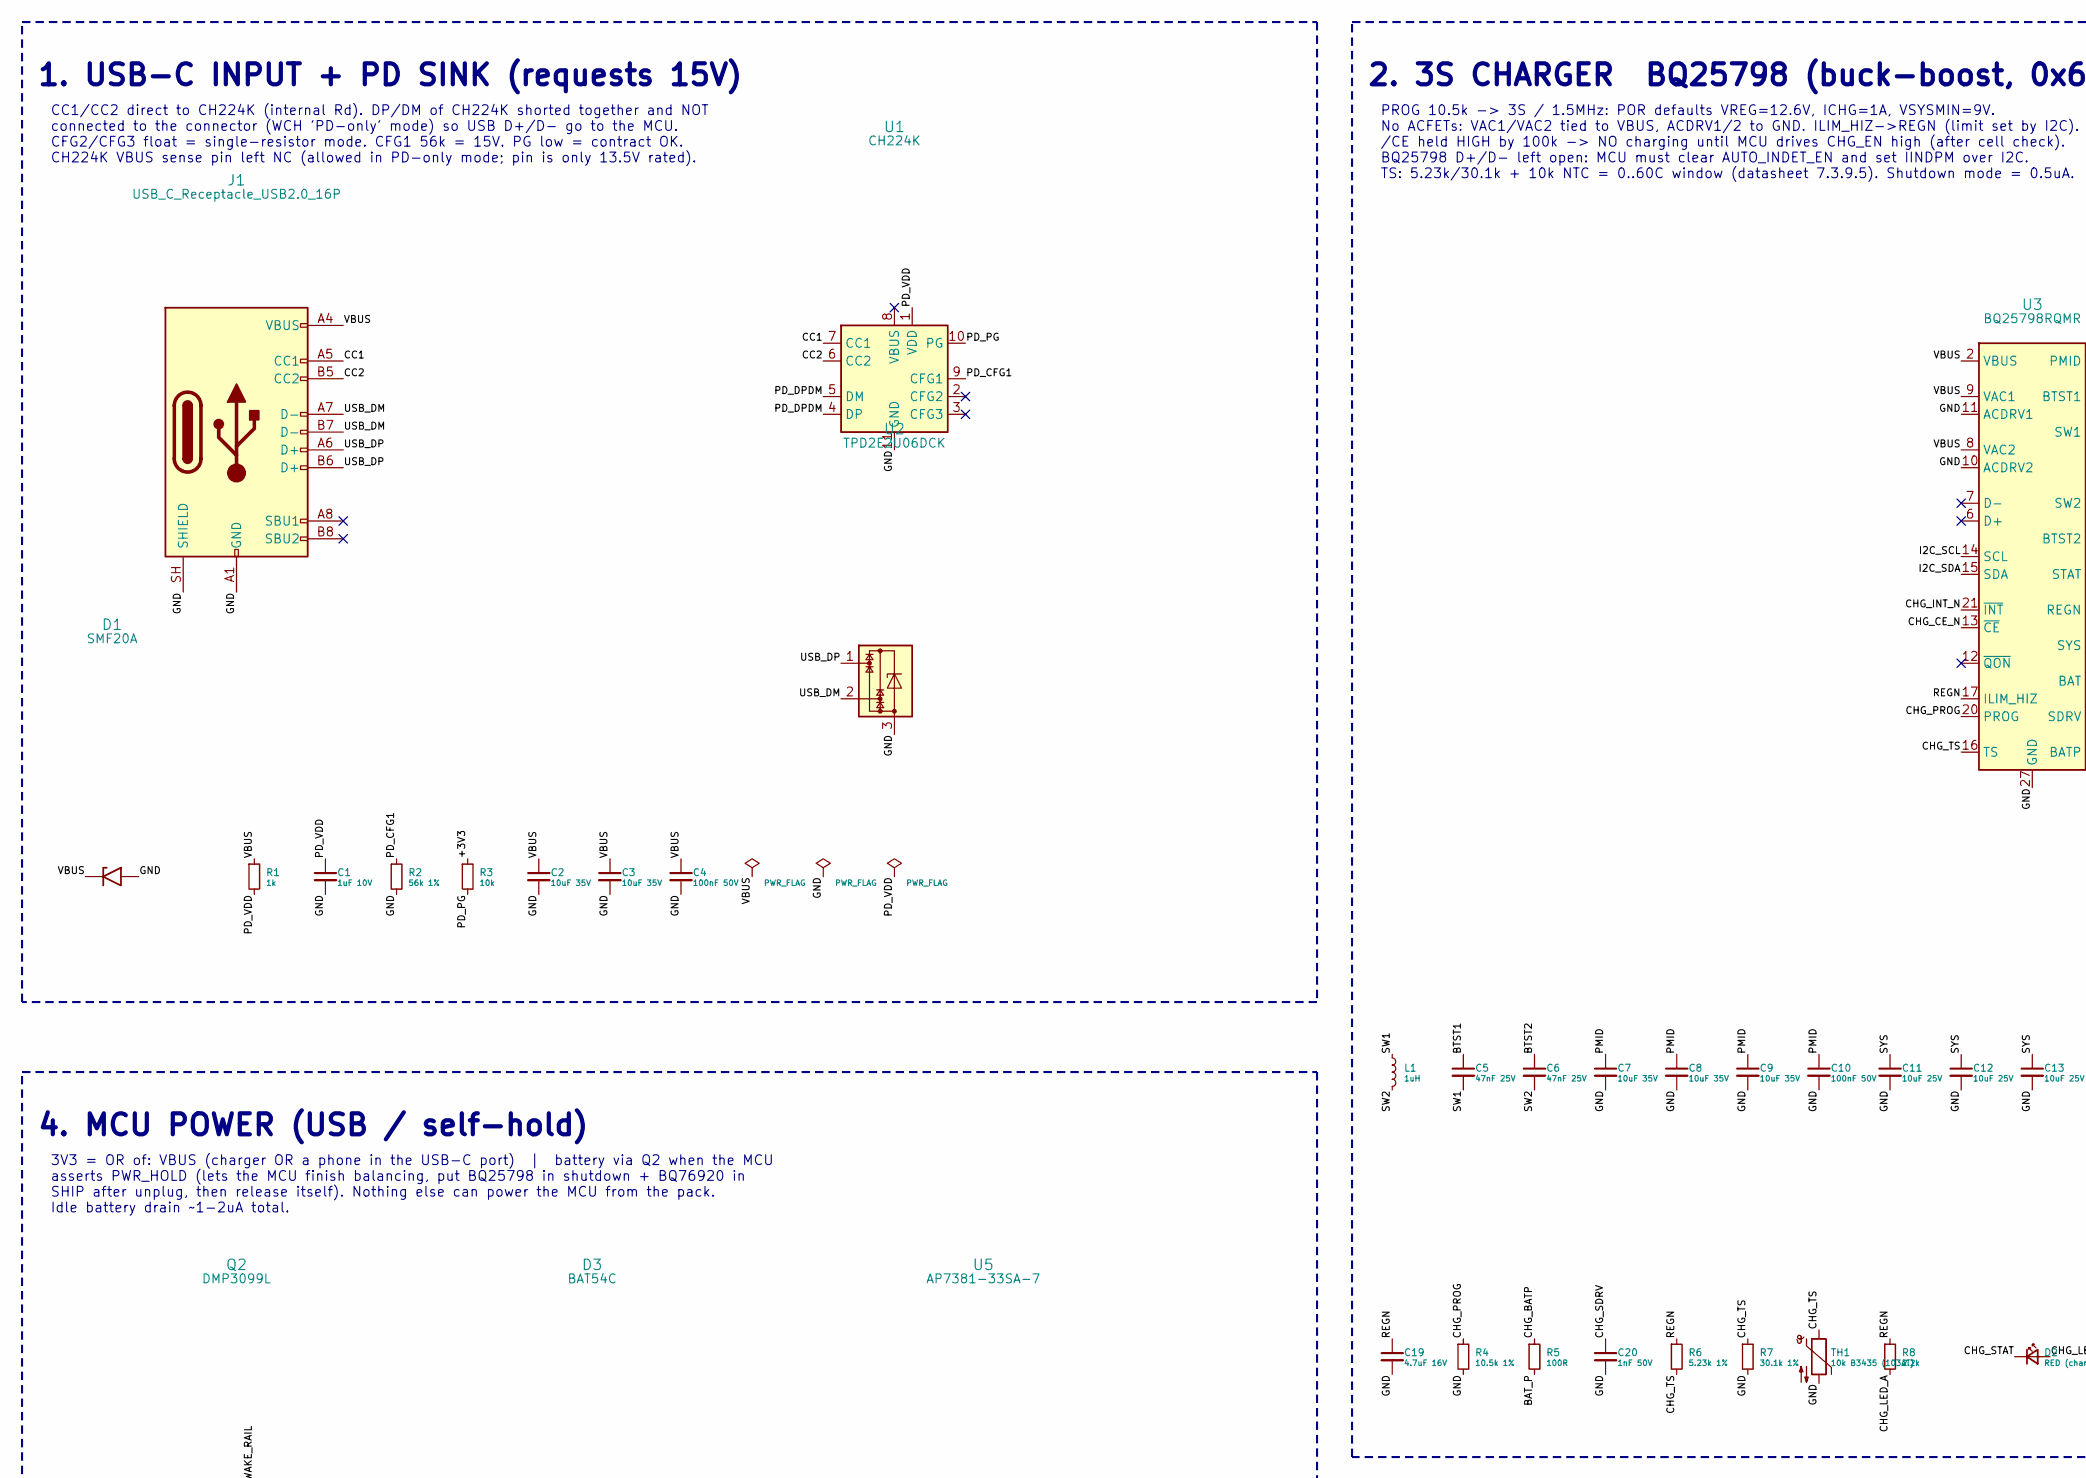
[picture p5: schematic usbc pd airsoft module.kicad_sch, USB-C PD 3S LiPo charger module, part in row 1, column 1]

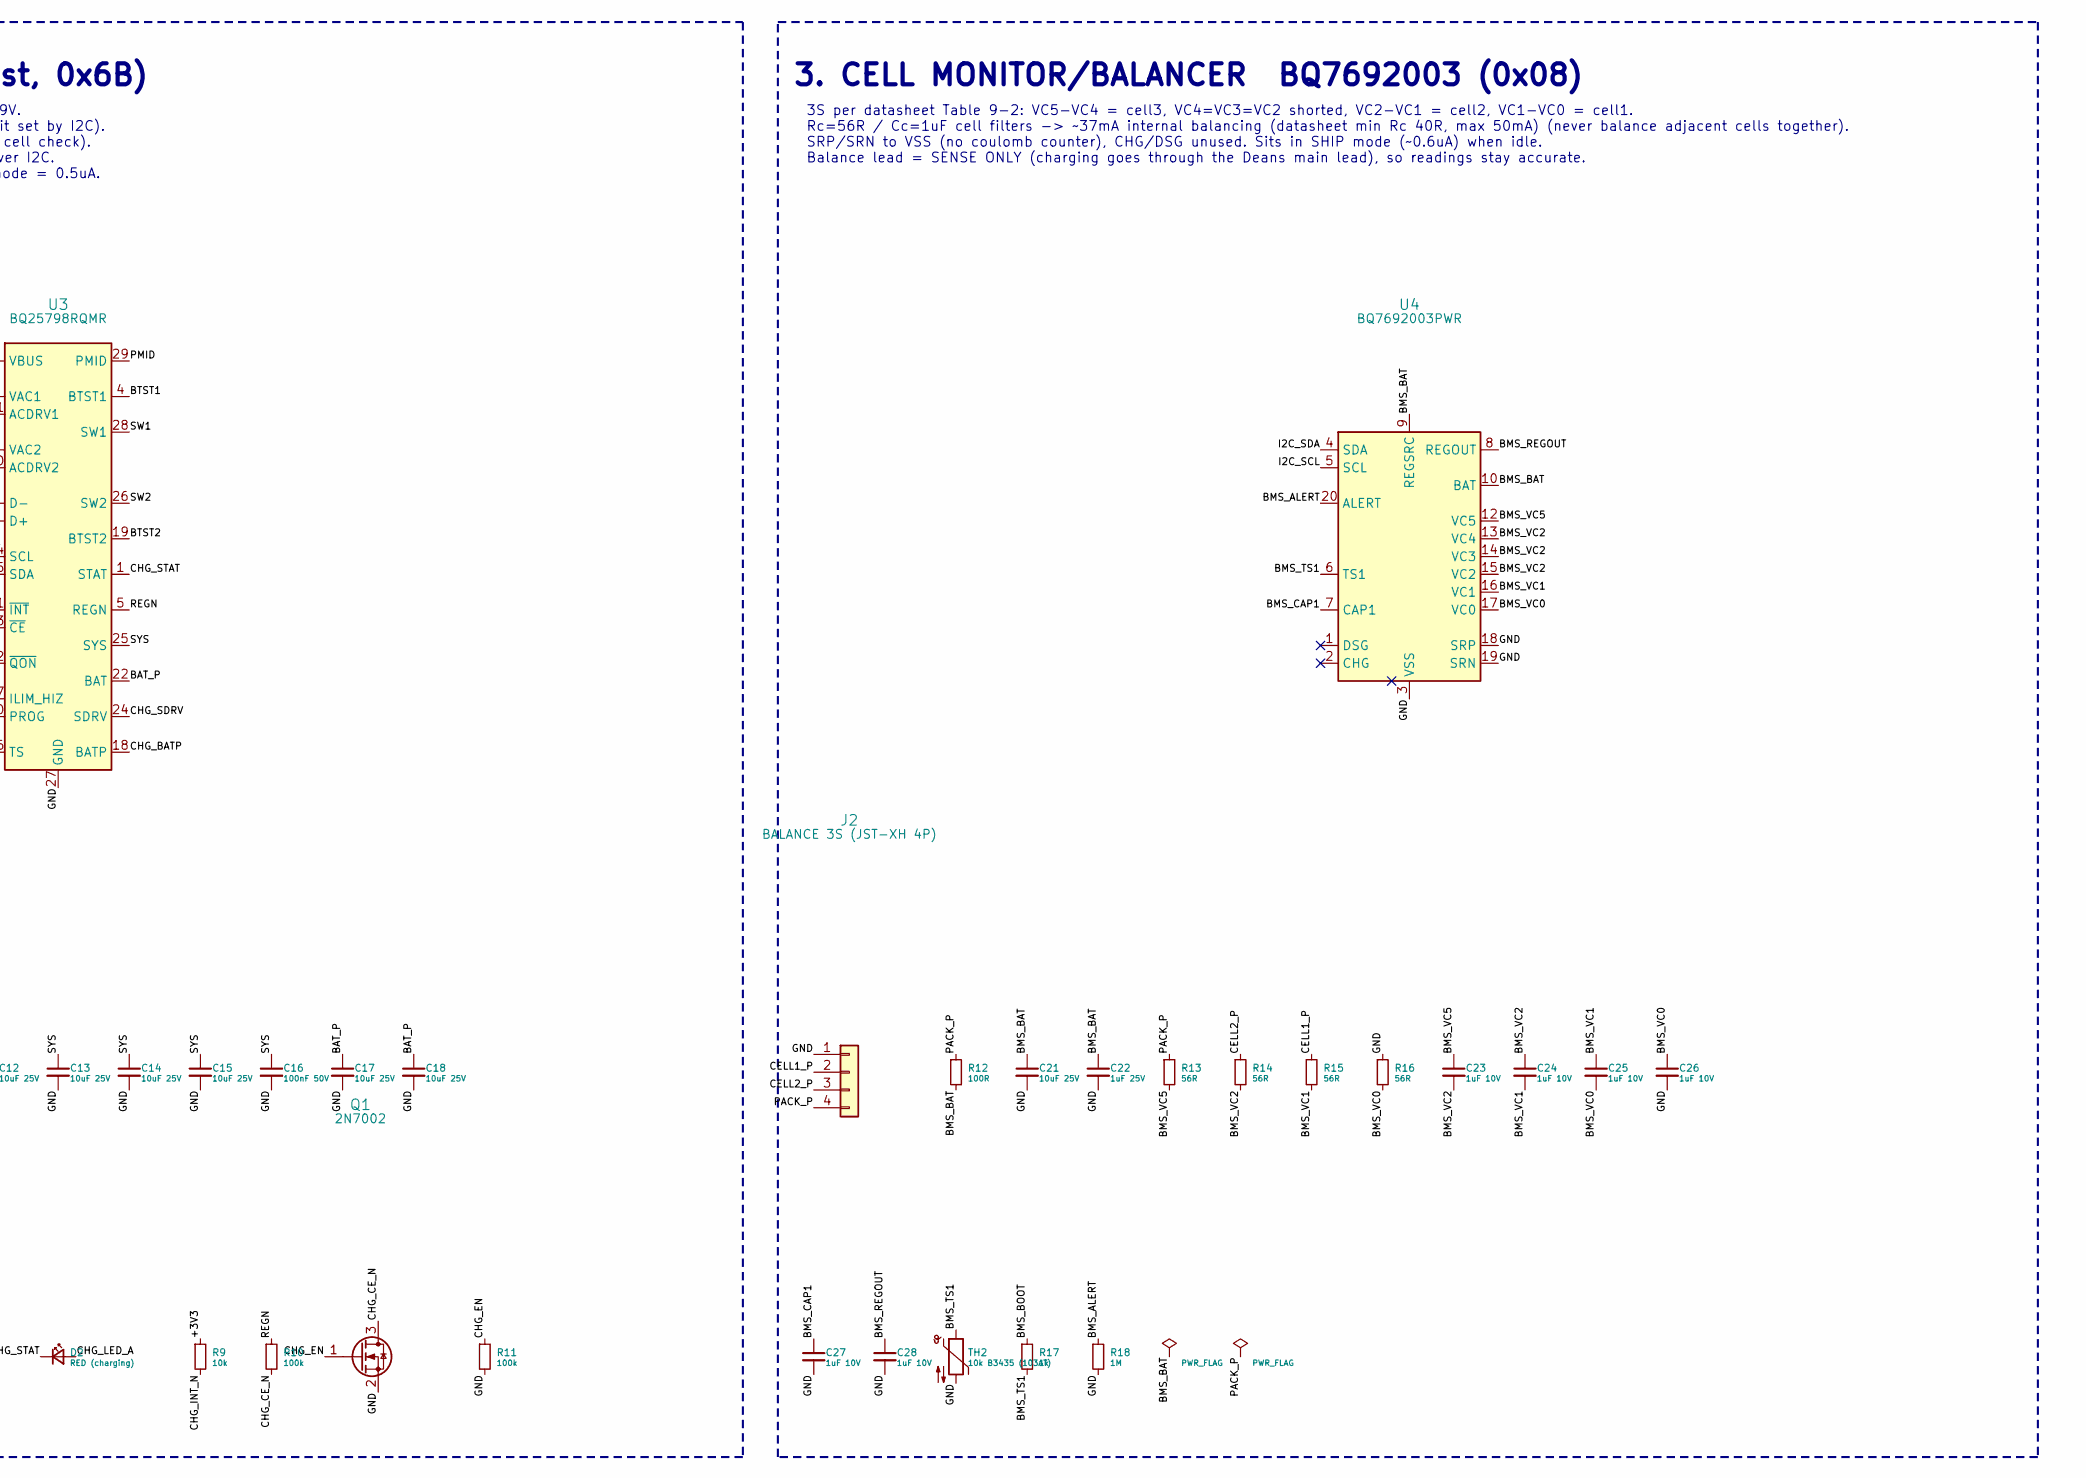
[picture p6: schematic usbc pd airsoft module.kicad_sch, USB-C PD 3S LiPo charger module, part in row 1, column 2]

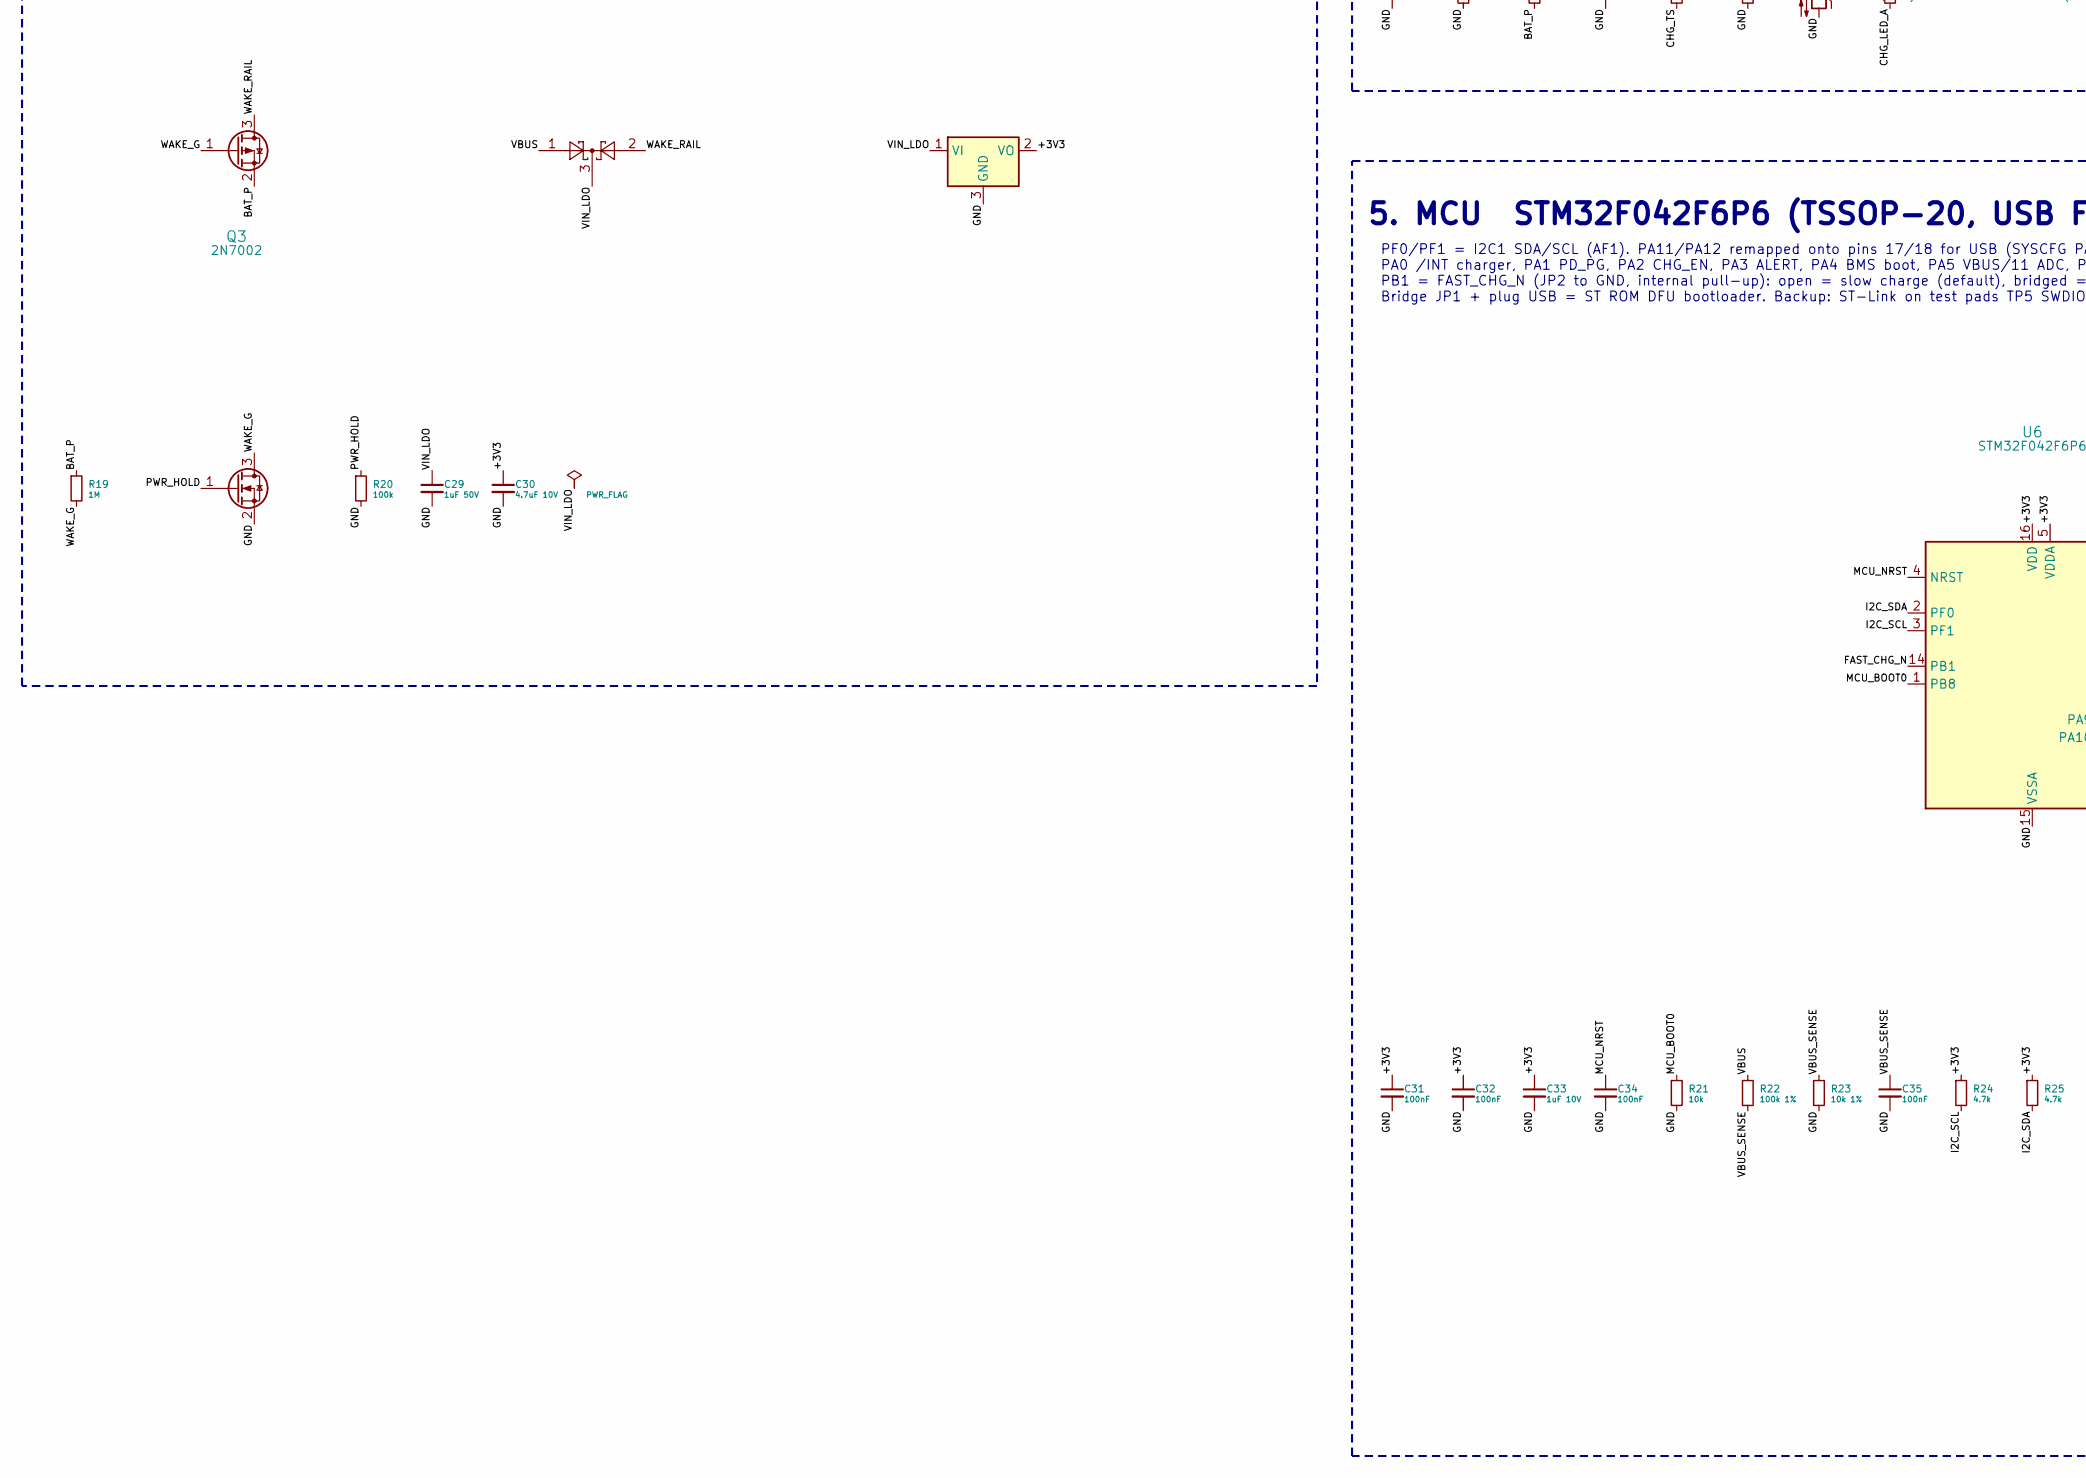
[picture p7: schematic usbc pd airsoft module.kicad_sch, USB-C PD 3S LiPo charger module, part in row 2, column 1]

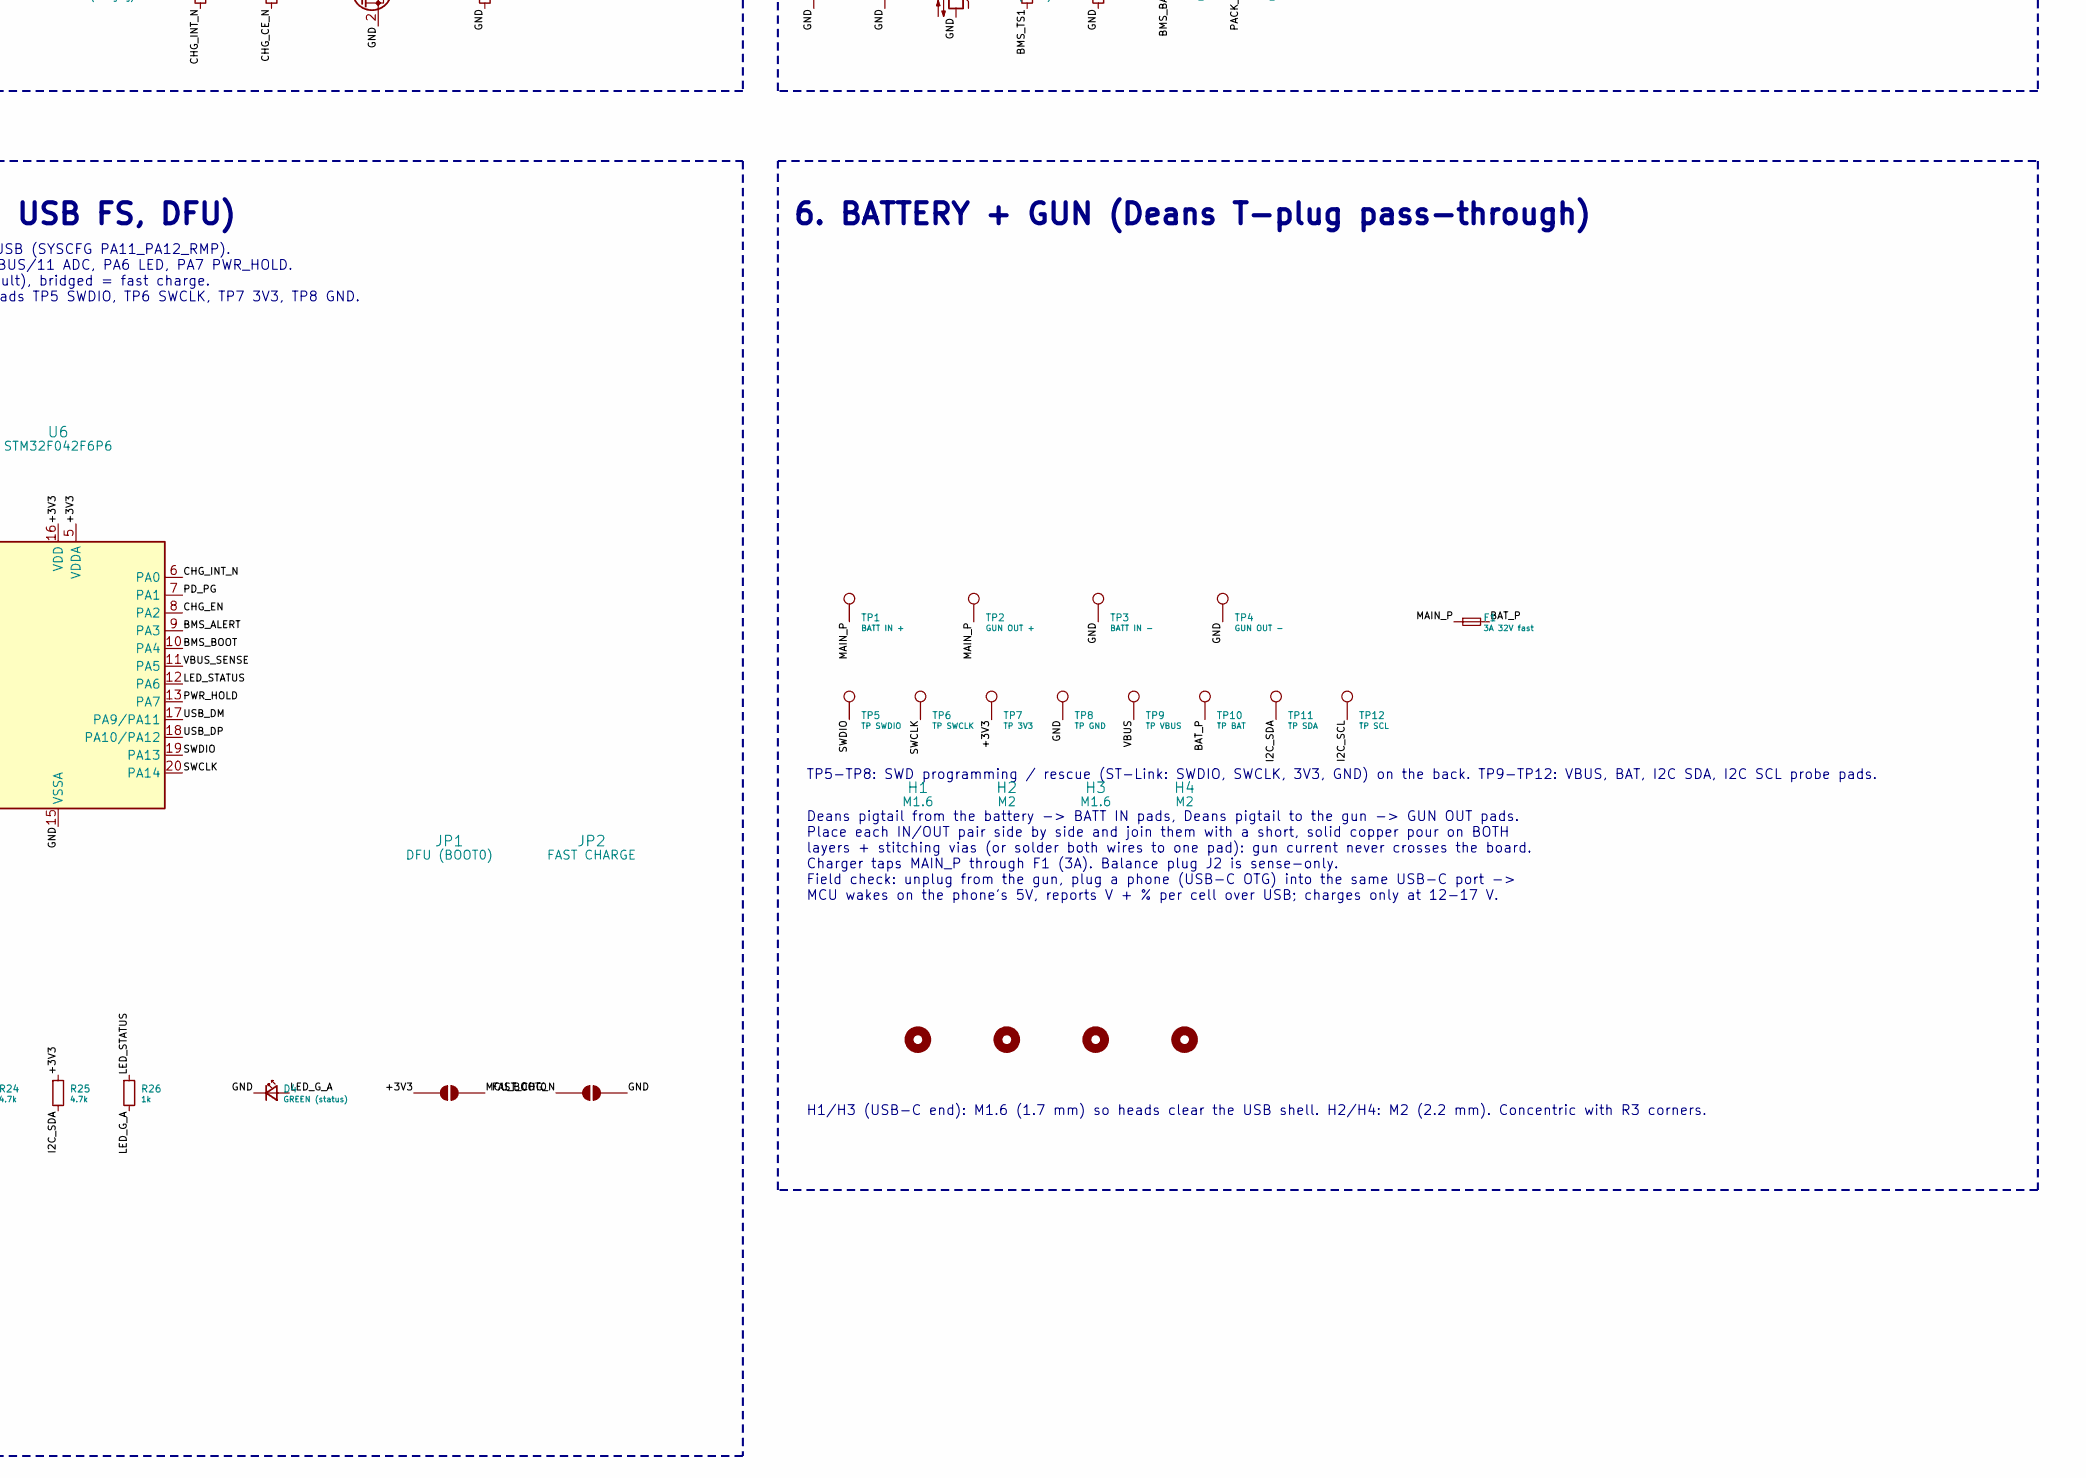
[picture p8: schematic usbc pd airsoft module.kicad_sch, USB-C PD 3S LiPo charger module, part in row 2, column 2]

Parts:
C1, C23, C24, C25, C26, C27, C28, C33: 1uF 10V; C_0402_1005Metric
C2, C3, C7, C8, C9: 10uF 35V; C_0805_2012Metric
C4, C10, C16: 100nF 50V; C_0402_1005Metric
C5, C6: 47nF 25V; C_0402_1005Metric
C11, C12, C13, C14, C15, C17, C18, C21: 10uF 25V; C_0805_2012Metric
C19: 4.7uF 16V; C_0603_1608Metric
C20: 1nF 50V; C_0402_1005Metric
C22: 1uF 25V; C_0603_1608Metric
C29: 1uF 50V; C_0805_2012Metric
C30: 4.7uF 10V; C_0603_1608Metric
C31, C32, C34, C35: 100nF; C_0402_1005Metric
D1: SMF20A; D_SMF; MPN Littelfuse SMF20A (20V TVS)
D2: RED (charging); LED_0603_1608Metric
D3: BAT54C; SOT-23
D4: GREEN (status); LED_0603_1608Metric
F1: 3A 32V fast; Fuse_1206_3216Metric; MPN Littelfuse 1206SFF300F/32 (any 3A >=32V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
H1, H3: M1.6; MountingHole_1.7mm_M1.6
H2, H4: M2; MountingHole_2.2mm_M2
J1: USB_C_Receptacle_USB2.0_16P; USB_C_Receptacle_HRO_TYPE-C-31-M-12; MPN HRO TYPE-C-31-M-12 (LCSC C165948)
J2: BALANCE 3S (JST-XH 4P); JST_XH_S4B-XH-SM4-TB_1x04-1MP_P2.50mm_Horizontal; MPN JST S4B-XH-SM4-TB
JP1: DFU (BOOT0); SolderJumper-2_P1.3mm_Open_RoundedPad1.0x1.5mm
JP2: FAST CHARGE; SolderJumper-2_P1.3mm_Open_RoundedPad1.0x1.5mm
L1: 1uH; L_Coilcraft_XAL4020-XXX; MPN Coilcraft XAL4020-102MEB
Q1, Q3: 2N7002; SOT-23
Q2: DMP3099L; SOT-23; MPN Diodes DMP3099L-7 (Vgs +-20V)
R1: 1k; R_1206_3216Metric
R2: 56k 1%; R_0402_1005Metric
R3, R9, R21: 10k; R_0402_1005Metric
R4: 10.5k 1%; R_0402_1005Metric
R5: 100R; R_0402_1005Metric
R6: 5.23k 1%; R_0402_1005Metric
R7: 30.1k 1%; R_0402_1005Metric
R8: 2.2k; R_0402_1005Metric
R10, R11, R20: 100k; R_0402_1005Metric
R12: 100R; R_0603_1608Metric
R13, R14, R15, R16: 56R; R_0603_1608Metric
R17, R26: 1k; R_0402_1005Metric
R18, R19: 1M; R_0402_1005Metric
R22: 100k 1%; R_0402_1005Metric
R23: 10k 1%; R_0402_1005Metric
R24, R25: 4.7k; R_0402_1005Metric
TH1, TH2: 10k B3435 (103AT); R_0402_1005Metric; MPN Murata NCP15XH103F03RC
TP1: BATT IN +; SolderWirePad_1x01_SMD_3x6mm
TP2: GUN OUT +; SolderWirePad_1x01_SMD_3x6mm
TP3: BATT IN -; SolderWirePad_1x01_SMD_3x6mm
TP4: GUN OUT -; SolderWirePad_1x01_SMD_3x6mm
TP5: TP SWDIO; TestPoint_Pad_D1.0mm
TP6: TP SWCLK; TestPoint_Pad_D1.0mm
TP7: TP 3V3; TestPoint_Pad_D1.0mm
TP8: TP GND; TestPoint_Pad_D1.0mm
TP9: TP VBUS; TestPoint_Pad_D1.0mm
TP10: TP BAT; TestPoint_Pad_D1.0mm
TP11: TP SDA; TestPoint_Pad_D1.0mm
TP12: TP SCL; TestPoint_Pad_D1.0mm
U1: CH224K; SSOP-10-1EP_3.9x4.9mm_P1mm_EP2.1x3.3mm; MPN WCH CH224K (LCSC C970725)
U2: TPD2E2U06DCK; SOT-323_SC-70; MPN TI TPD2E2U06DCKR
U3: BQ25798RQMR; Texas_RQM0029A_VQFN-29_4x4mm_P0.4mm; MPN TI BQ25798RQMR
U4: BQ7692003PWR; TSSOP-20_4.4x6.5mm_P0.65mm; MPN TI BQ7692003PWR (3.3V LDO, addr 0x08, C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
U5: AP7381-33SA-7; SOT-23; MPN Diodes AP7381-33SA-7 (40V in)
U6: STM32F042F6P6; TSSOP-20_4.4x6.5mm_P0.65mm; MPN ST STM32F042F6P6

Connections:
/+3V3: C30.1, C31.1, C32.1, C33.1, JP1.1 (A), R3.1, R9.1, R24.1, R25.1, TP7.1, U5.2 (VO), U6.5 (VDDA), U6.16 (VDD)
/BAT_P: C17.1, C18.1, F1.2, Q2.2 (S), R5.2, R19.1, TP10.1, U3.22 (BAT), U3.23 (BAT)
/BMS_ALERT: R18.1, U4.20 (ALERT), U6.9 (PA3)
/BMS_BAT: C21.1, C22.1, R12.2, U4.9 (REGSRC), U4.10 (BAT)
/BMS_BOOT: R17.1, U6.10 (PA4)
/BMS_CAP1: C27.1, U4.7 (CAP1)
/BMS_REGOUT: C28.1, U4.8 (REGOUT)
/BMS_TS1: R17.2, TH2.1, U4.6 (TS1)
/BMS_VC0: C25.2, C26.1, R16.2, U4.17 (VC0)
/BMS_VC1: C24.2, C25.1, R15.2, U4.16 (VC1)
/BMS_VC2: C23.2, C24.1, R14.2, U4.13 (VC4), U4.14 (VC3), U4.15 (VC2)
/BMS_VC5: C23.1, R13.2, U4.12 (VC5)
/BTST1: C5.1, U3.4 (BTST1)
/BTST2: C6.1, U3.19 (BTST2)
/CC1: J1.A5 (CC1), U1.7 (CC1)
/CC2: J1.B5 (CC2), U1.6 (CC2)
/CELL1_P: J2.2, R15.1
/CELL2_P: J2.3, R14.1
/CHG_BATP: R5.1, U3.18 (BATP)
/CHG_CE_N: Q1.3 (D), R10.2, U3.13 (~CE)
/CHG_EN: Q1.1 (G), R11.1, U6.8 (PA2)
/CHG_INT_N: R9.2, U3.21 (~INT), U6.6 (PA0)
/CHG_LED_A: D2.2 (A), R8.2
/CHG_PROG: R4.1, U3.20 (PROG)
/CHG_SDRV: C20.1, U3.24 (SDRV)
/CHG_STAT: D2.1 (K), U3.1 (STAT)
/CHG_TS: R6.2, R7.1, TH1.1, U3.16 (TS)
/FAST_CHG_N: JP2.1 (A), U6.14 (PB1)
/GND: C1.2, C2.2, C3.2, C4.2, C7.2, C8.2, C9.2, C10.2, C11.2, C12.2, C13.2, C14.2, C15.2, C16.2, C17.2, C18.2, C19.2, C20.2, C21.2, C22.2, C26.2, C27.2, C28.2, C29.2, C30.2, C31.2, C32.2, C33.2, C34.2, C35.2, D1.2 (A2), D4.1 (K), J1.A1 (GND), J1.A12 (GND), J1.B1 (GND), J1.B12 (GND), J1.SH (SHIELD), J2.1, JP2.2 (B), Q1.2 (S), Q3.2 (S), R2.2, R4.2, R7.2, R11.2, R16.1, R18.2, R20.2, R21.2, R23.2, TH1.2, TH2.2, TP3.1, TP4.1, TP8.1, U1.11 (GND), U2.3, U3.10 (ACDRV2), U3.11 (ACDRV1), U3.27 (GND), U4.3 (VSS), U4.18 (SRP), U4.19 (SRN), U5.3 (GND), U6.15 (VSSA)
/I2C_SCL: R24.2, TP12.1, U3.14 (SCL), U4.5 (SCL), U6.3 (PF1)
/I2C_SDA: R25.2, TP11.1, U3.15 (SDA), U4.4 (SDA), U6.2 (PF0)
/LED_G_A: D4.2 (A), R26.2
/LED_STATUS: R26.1, U6.12 (PA6)
/MAIN_P: F1.1, TP1.1, TP2.1
/MCU_BOOT0: JP1.2 (B), R21.1, U6.1 (PB8)
/MCU_NRST: C34.1, U6.4 (NRST)
/PACK_P: J2.4, R12.1, R13.1
/PD_CFG1: R2.1, U1.9 (CFG1)
/PD_DPDM: U1.4 (DP), U1.5 (DM)
/PD_PG: R3.2, U1.10 (PG), U6.7 (PA1)
/PD_VDD: C1.1, R1.2, U1.1 (VDD)
/PMID: C7.1, C8.1, C9.1, C10.1, U3.29 (PMID)
/PWR_HOLD: Q3.1 (G), R20.1, U6.13 (PA7)
/REGN: C19.1, R6.1, R8.1, R10.1, U3.5 (REGN), U3.17 (ILIM_HIZ)
/SW1: C5.2, L1.1, U3.28 (SW1)
/SW2: C6.2, L1.2, U3.26 (SW2)
/SWCLK: TP6.1, U6.20 (PA14)
/SWDIO: TP5.1, U6.19 (PA13)
/SYS: C11.1, C12.1, C13.1, C14.1, C15.1, C16.1, U3.25 (SYS)
/USB_DM: J1.A7 (D-), J1.B7 (D-), U2.2, U6.17 (PA9/PA11)
/USB_DP: J1.A6 (D+), J1.B6 (D+), U2.1, U6.18 (PA10/PA12)
/VBUS: C2.1, C3.1, C4.1, D1.1 (A1), D3.1, J1.A4 (VBUS), J1.A9 (VBUS), J1.B4 (VBUS), J1.B9 (VBUS), R1.1, R22.1, TP9.1, U3.2 (VBUS), U3.3 (VBUS), U3.8 (VAC2), U3.9 (VAC1)
/VBUS_SENSE: C35.1, R22.2, R23.1, U6.11 (PA5)
/VIN_LDO: C29.1, D3.3, U5.1 (VI)
/WAKE_G: Q2.1 (G), Q3.3 (D), R19.2
/WAKE_RAIL: D3.2, Q2.3 (D)

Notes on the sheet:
1. USB-C INPUT + PD SINK (requests 15V)
CC1/CC2 direct to CH224K (internal Rd). DP/DM of CH224K shorted together and NOT connected to the connector (WCH 'PD-only' mode) so USB D+/D- go to the MCU. CFG2/CFG3 float = single-resistor mode. CFG1 56k = 15V. PG low = contract OK. CH224K VBUS sense pin left NC (allowed in PD-only mode; pin is o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
2. 3S CHARGER BQ25798 (buck-boost, 0x6B)
PROG 10.5k -> 3S / 1.5MHz: POR defaults VREG=12.6V, ICHG=1A, VSYSMIN=9V. No ACFETs: VAC1/VAC2 tied to VBUS, ACDRV1/2 to GND. ILIM_HIZ->REGN (limit set by I2C). /CE held HIGH by 100k -> NO charging until MCU drives CHG_EN high (after cell check). BQ25798 D+/D- left open: MCU must clear AUTO_INDET_EN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
3. CELL MONITOR/BALANCER BQ7692003 (0x08)
3S per datasheet Table 9-2: VC5-VC4 = cell3, VC4=VC3=VC2 shorted, VC2-VC1 = cell2, VC1-VC0 = cell1. Rc=56R / Cc=1uF cell filters -> ~37mA internal balancing (datasheet min Rc 40R, max 50mA) (never balance adjacent cells together). SRP/SRN to VSS (no coulomb counter), CHG/DSG unused. Sits in SHIP mo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
4. MCU POWER (USB / self-hold)
3V3 = OR of: VBUS (charger OR a phone in the USB-C port) | battery via Q2 when the MCU asserts PWR_HOLD (lets the MCU finish balancing, put BQ25798 in shutdown + BQ76920 in SHIP after unplug, then release itself). Nothing else can power the MCU from the pack. Idle battery drain ~1-2uA total.
5. MCU STM32F042F6P6 (TSSOP-20, USB FS, DFU)
PF0/PF1 = I2C1 SDA/SCL (AF1). PA11/PA12 remapped onto pins 17/18 for USB (SYSCFG PA11_PA12_RMP). PA0 /INT charger, PA1 PD_PG, PA2 CHG_EN, PA3 ALERT, PA4 BMS boot, PA5 VBUS/11 ADC, PA6 LED, PA7 PWR_HOLD. PB1 = FAST_CHG_N (JP2 to GND, internal pull-up): open = slow charge (default), bridged = fast ch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
6. BATTERY + GUN (Deans T-plug pass-through)
Deans pigtail from the battery -> BATT IN pads, Deans pigtail to the gun -> GUN OUT pads. Place each IN/OUT pair side by side and join them with a short, solid copper pour on BOTH layers + stitching vias (or solder both wires to one pad): gun current never crosses the board. Charger taps MAIN_P thr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
H1/H3 (USB-C end): M1.6 (1.7 mm) so heads clear the USB shell. H2/H4: M2 (2.2 mm). Concentric with R3 corners.
TP5-TP8: SWD programming / rescue (ST-Link: SWDIO, SWCLK, 3V3, GND) on the back. TP9-TP12: VBUS, BAT, I2C SDA, I2C SCL probe pads.

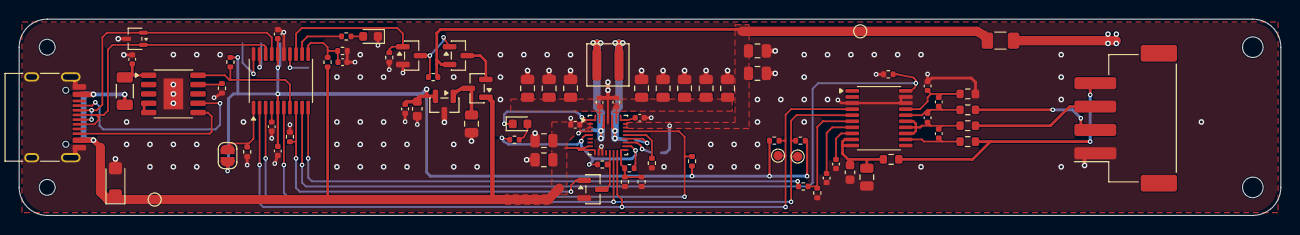
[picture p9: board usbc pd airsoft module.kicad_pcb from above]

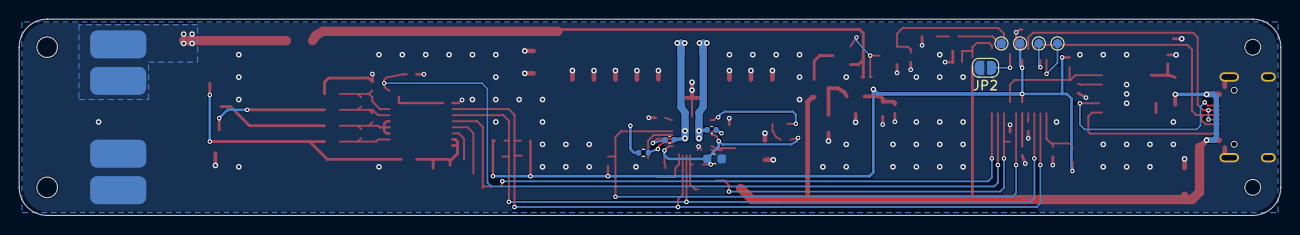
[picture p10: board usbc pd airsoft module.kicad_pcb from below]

Board: 2 copper layers, 135.0 x 21.0 mm, 98 parts (13 on the bottom side), 56 nets.

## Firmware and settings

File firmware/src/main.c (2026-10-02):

// Airsoft PD charger firmware - STM32F042F6P6
#include <string.h>
#include "stm32f0xx.h"
#include "tusb.h"
#include "hw.h"
#include "config.h"
#include "app.h"

void USB_IRQHandler(void) { tud_int_handler(0); }
uint32_t tusb_time_millis_api(void) { return millis(); }

void usb_send(const char *s) {
    if (!tud_cdc_connected()) return;
    uint32_t n = (uint32_t)strlen(s), t = millis();
    while (n && millis() - t < 50) {
        uint32_t k = tud_cdc_write(s, n);
        s += k; n -= k;
        tud_cdc_write_flush();
        tud_task();
    }
}

// keep USB alive during the few blocking waits (cell monitor boot, reboot replies)
static bool in_delay;
void delay_hook(void) {
    if (in_delay) return;
    in_delay = true;
    tud_task();
    wdg_feed();
    in_delay = false;
}

static char rx[96];
static uint8_t rx_len;

static void usb_poll_rx(void) {
    while (tud_cdc_available()) {
        char c = (char)tud_cdc_read_char();
        if (c == '\r') continue;
        if (c == '\n') { rx[rx_len] = 0; app_command(rx); rx_len = 0; }
        else if (rx_len < sizeof rx - 1) rx[rx_len++] = c;
    }
}

int main(void) {
    hw_init();
    config_load();
    app_init();
    tusb_rhport_init_t dev = {.role = TUSB_ROLE_DEVICE, .speed = TUSB_SPEED_AUTO};
    tusb_init(0, &dev);
    wdg_init();

    uint32_t t_tick = 0;
    char status[360];
    while (1) {
        wdg_feed();
        app_fast();
        tud_task();
        usb_poll_rx();
        if (tud_mounted()) app_host_seen();     // a PD wall charger never enumerates us; a phone/PC does
        if (millis() - t_tick >= 250) { t_tick = millis(); app_tick(); }
        app_led();
        if (app_report_due() && tud_cdc_connected()) {
            app_status_json(status, sizeof status);
            usb_send(status);
        }
    }
}

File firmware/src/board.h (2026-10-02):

// Airsoft PD charger - board pin map (STM32F042F6P6, TSSOP-20), matches schematic Rev A
#pragma once

// GPIOA
#define PIN_CHG_INT_N   0   // PA0  in  : BQ25798 /INT (open drain, 10k pull-up)
#define PIN_PD_PG       1   // PA1  in  : CH224K PG (low = PD contract ok)
#define PIN_CHG_EN      2   // PA2  out : high -> Q1 pulls BQ25798 /CE low -> charging allowed
#define PIN_BMS_ALERT   3   // PA3  in  : BQ76920 ALERT (1M pull-down)
#define PIN_BMS_BOOT    4   // PA4  out : pulse high ~5 ms to boot BQ76920 from SHIP (via 1k into TS1)
#define PIN_VBUS_SENSE  5   // PA5  adc : VBUS / 11 (100k / 10k divider) -> ADC_IN5
#define PIN_LED         6   // PA6  pwm : green status LED (TIM3_CH1, AF1)
#define PIN_PWR_HOLD    7   // PA7  out : high keeps the MCU powered from the pack after USB is unplugged
// PA11/PA12 = USB DM/DP (pins 17/18, remapped), PA13/PA14 = SWD
// GPIOB
#define PIN_FAST_N      1   // PB1  in  : JP2 solder jumper to GND (internal pull-up). open = slow charge, bridged = fast
// GPIOF
#define PIN_I2C_SDA     0   // PF0 I2C1_SDA (AF1)
#define PIN_I2C_SCL     1   // PF1 I2C1_SCL (AF1)

#define VBUS_DIV        11u      // (100k + 10k) / 10k
#define VBUS_MAX_MV     17000u   // above this USB voltage charging is cut immediately (CH224K should give 15 V)
#define I2C_ADDR_BQ25798 0x6B
#define I2C_ADDR_BQ76920 0x08    // BQ7692003: 3.3 V REGOUT, address 0x08, CRC enabled

#define FW_VERSION      "1.0.0"
#define HW_VERSION      "RevA"

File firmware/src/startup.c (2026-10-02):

// Minimal startup for STM32F042x6 (Cortex-M0): vector table + reset handler, no assembler needed
#include <stdint.h>

extern uint32_t _sidata, _sdata, _edata, _sbss, _ebss, _estack;
extern int main(void);
extern void boot_check(void);

void Reset_Handler(void);
void Default_Handler(void) { while (1) {} }

#define WEAK __attribute__((weak, alias("Default_Handler")))
void NMI_Handler(void) WEAK;
void HardFault_Handler(void) WEAK;
void SVC_Handler(void) WEAK;
void PendSV_Handler(void) WEAK;
void SysTick_Handler(void) WEAK;
void WWDG_IRQHandler(void) WEAK;
void PVD_VDDIO2_IRQHandler(void) WEAK;
void RTC_IRQHandler(void) WEAK;
void FLASH_IRQHandler(void) WEAK;
void RCC_CRS_IRQHandler(void) WEAK;
void EXTI0_1_IRQHandler(void) WEAK;
void EXTI2_3_IRQHandler(void) WEAK;
void EXTI4_15_IRQHandler(void) WEAK;
void TSC_IRQHandler(void) WEAK;
void DMA1_Channel1_IRQHandler(void) WEAK;
void DMA1_Channel2_3_IRQHandler(void) WEAK;
void DMA1_Channel4_5_IRQHandler(void) WEAK;
void ADC1_IRQHandler(void) WEAK;
void TIM1_BRK_UP_TRG_COM_IRQHandler(void) WEAK;
void TIM1_CC_IRQHandler(void) WEAK;
void TIM2_IRQHandler(void) WEAK;
void TIM3_IRQHandler(void) WEAK;
void TIM14_IRQHandler(void) WEAK;
void TIM16_IRQHandler(void) WEAK;
void TIM17_IRQHandler(void) WEAK;
void I2C1_IRQHandler(void) WEAK;
void SPI1_IRQHandler(void) WEAK;
void SPI2_IRQHandler(void) WEAK;
void USART1_IRQHandler(void) WEAK;
void USART2_IRQHandler(void) WEAK;
void CEC_CAN_IRQHandler(void) WEAK;
void USB_IRQHandler(void) WEAK;

__attribute__((section(".isr_vector"), used))
void (*const g_vectors[])(void) = {
    (void (*)(void))&_estack, Reset_Handler, NMI_Handler, HardFault_Handler,
    0, 0, 0, 0, 0, 0, 0, SVC_Handler, 0, 0, PendSV_Handler, SysTick_Handler,
    WWDG_IRQHandler, PVD_VDDIO2_IRQHandler, RTC_IRQHandler, FLASH_IRQHandler,
    RCC_CRS_IRQHandler, EXTI0_1_IRQHandler, EXTI2_3_IRQHandler, EXTI4_15_IRQHandler,
    TSC_IRQHandler, DMA1_Channel1_IRQHandler, DMA1_Channel2_3_IRQHandler, DMA1_Channel4_5_IRQHandler,
    ADC1_IRQHandler, TIM1_BRK_UP_TRG_COM_IRQHandler, TIM1_CC_IRQHandler, TIM2_IRQHandler,
    TIM3_IRQHandler, 0, 0, TIM14_IRQHandler,
    0, TIM16_IRQHandler, TIM17_IRQHandler, I2C1_IRQHandler,
    0, SPI1_IRQHandler, SPI2_IRQHandler, USART1_IRQHandler,
    USART2_IRQHandler, 0, CEC_CAN_IRQHandler, USB_IRQHandler,
};

void Reset_Handler(void) {
    boot_check();                       // jumps to the ROM DFU bootloader if requested before reset
    uint32_t *src = &_sidata, *dst = &_sdata;
    while (dst < &_edata) *dst++ = *src++;
    for (dst = &_sbss; dst < &_ebss;) *dst++ = 0;
    main();
    while (1) {}
}

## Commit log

2026-10-02 Add complete USB-C PD 3S LiPo charger module
    Hardware (KiCad 10): schematic, routed 135x21 mm 2-layer PCB, BOM,
    design notes. CH224K 15 V PD sink, BQ25798 buck-boost charger,
    BQ7692003 cell monitor, STM32F042F6P6 MCU, JP2 fast/slow jumper.
    Firmware: bare-metal STM32F042 + TinyUSB CDC. 12-17 V charge window
    with instant over-voltage cut, per-cell charge control, charge plans,
    flash event log with per-charge reports.
    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
    [base.kicad_pcb, bom.csv, usbc pd airsoft module.kicad_pcb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]
2026-10-02 Fix issues found in full code review
    Firmware:
    - Enable the USB peripheral clock (RCC USBEN). TinyUSB leaves this to
    the board code; without it USB never enumerates.
    - Re-sync cell balancing with the BQ76920 read-back: the chip clears
    CELLBALx on its own after some events.
    - Set BQ25798 input OVP to 18 V as a hardware backstop behind the 17 V
    firmware cut (re-applied with the periodic config refresh).
    - Default input current limit 1.5 A so 18-20 W PD chargers stay within
    rating during fast charge.
    Android app:
    - Run USB writes on the IO dispatcher instead of the UI thread.
    - Detect an unplugged device in the reader loop instead of spinning.
    - Lock the event-log buffer shared by the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
    [bq25798.c]
2026-10-02 Add production files: Gerbers, drill, pick-and-place, assembly drawings, ordering notes
    [bom.csv, pick-and-place.csv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]
2026-10-02 App: top-right auto-hiding notifications; save charge plan quietly and debounced
2026-10-02 Add verified LCSC/JLCPCB BOMs and full production zip
    [bom_jlcpcb.csv, bom_lcsc.csv]
2026-10-02 BOM: U5 AP7381-33SA-7 moved to buy-elsewhere list (LCSC listing discontinued), 100nF line to C6119778, ordering notes
    [bom_jlcpcb.csv, bom_lcsc.csv, parts_not_at_lcsc.csv]
